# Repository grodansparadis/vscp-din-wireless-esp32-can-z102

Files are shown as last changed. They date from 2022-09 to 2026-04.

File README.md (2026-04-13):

# vscp-din-wireless-esp32-can-z102



This board has secure wireless wifi gateway functionality for a remote **CAN4VSCP** bus.

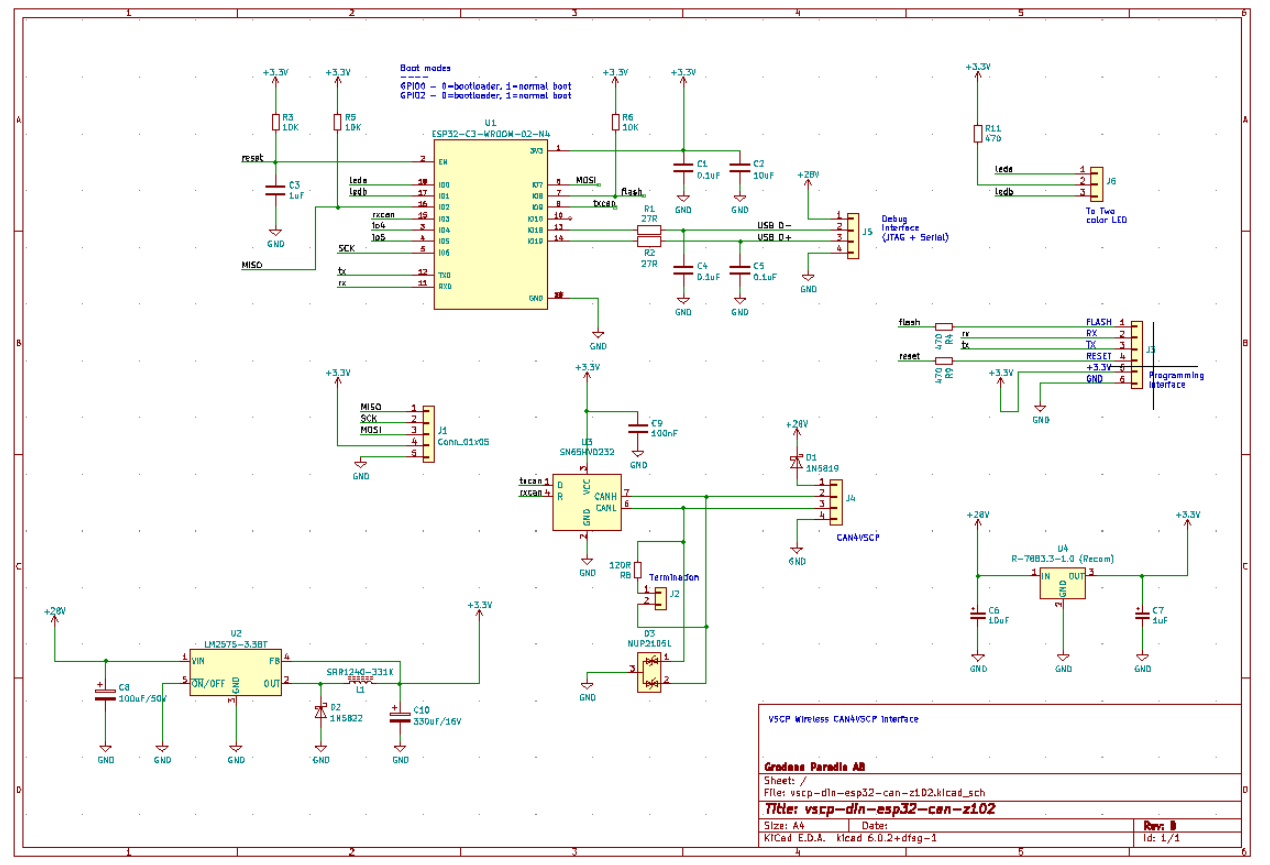
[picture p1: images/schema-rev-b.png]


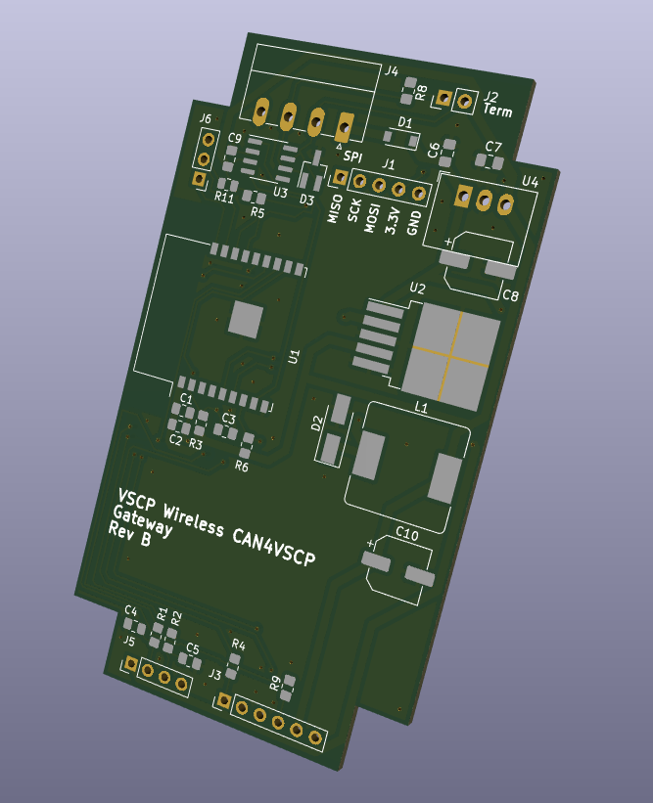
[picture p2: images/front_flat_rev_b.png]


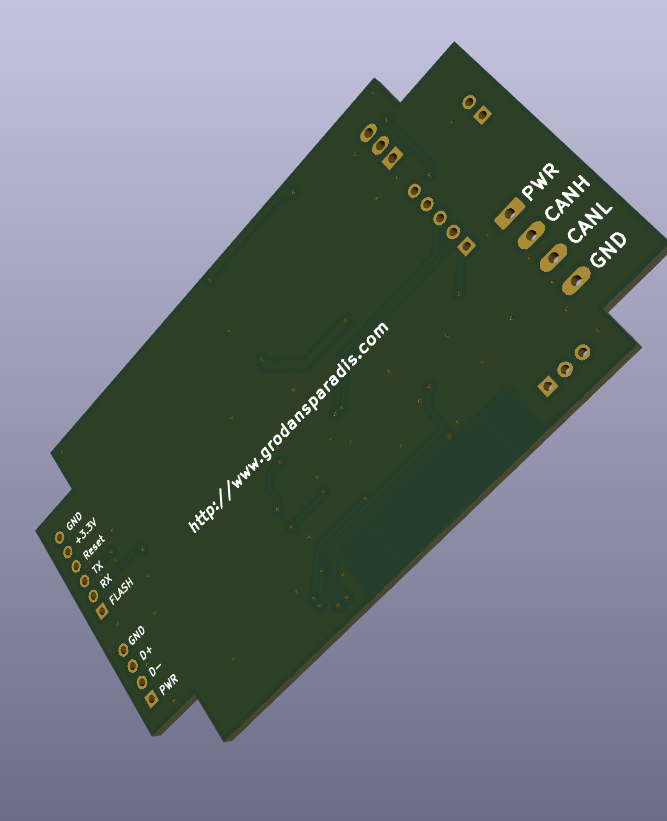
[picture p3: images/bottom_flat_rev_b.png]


Part of the [VSCP Project](https://www.vscp.org).

Copyright 2021-2026 (C) Åke Hedman, [https://www.grodansparadis.com](Grodans Paradis AB)
Licensed under the MIT License. See LICENSE file in the project root for full license information.

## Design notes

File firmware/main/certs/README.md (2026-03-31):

# Certificates Directory Convention

Certificate and key file convention for this directory:

- Tracked example or demo material should use the suffix `.example.pem`.
- Real local private keys should use either `prvtkey.pem` or `*.local.pem` and must stay untracked.
- Public demo certificates may be tracked when they are intentionally non-sensitive.

Recommended usage:

1. Keep tracked examples clearly marked, such as `prvtkey.example.pem`.
2. Copy an example to a local filename before use.
3. Never commit real private key contents to this repository.

Examples:

- `prvtkey.example.pem`: tracked placeholder or demo key material.
- `prvtkey.pem`: local private key, ignored by git.
- `device-cert.local.pem`: local certificate or key material, ignored by git.

The focused Codacy and Trivy setup assumes that tracked files in this directory are examples or public material, while real private keys remain local only.

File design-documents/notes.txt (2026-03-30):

Internal product page: http://192.168.1.7/wiki/doku.php?id=vscp-din-esp32-can-z102

openocd -f board/esp32c3-builtin.cfg

node test_ws1.js --url ws://192.168.1.100:8884/ws1

------------------------------------------------------
                       Security
------------------------------------------------------

https://community.letsencrypt.org/t/how-to-install-certificate-on-a-microcontroller/197377
Certificat bundle: https://docs.espressif.com/projects/esp-idf/en/stable/esp32/api-reference/protocols/esp_https_server.html

httpd_handle_t
start_webserver(void)
{
  httpd_handle_t srv     = NULL;
  httpd_ssl_config_t cfg = HTTPD_SSL_CONFIG_DEFAULT();
  cfg.port_insecure = g_persistent.webPort;
  cfg.httpd.server_port = g_persistent.webPort;

  // 4096 is to low for OTA
  cfg.httpd.stack_size = 1024 * 5;

  cfg.httpd.lru_purge_enable = true;
  // Use the URI wildcard matching function in order to
  // allow the same handler to respond to multiple different
  // target URIs which match the wildcard scheme
  cfg.httpd.uri_match_fn = httpd_uri_match_wildcard;

  cfg.httpd.max_uri_handlers = 20;

  extern const unsigned char servercert_start[] asm("_binary_servercert_pem_start");
  extern const unsigned char servercert_end[] asm("_binary_servercert_pem_end");
  cfg.servercert     = servercert_start;
  cfg.servercert_len = servercert_end - servercert_start;

  extern const unsigned char prvtkey_pem_start[] asm("_binary_prvtkey_pem_start");
  extern const unsigned char prvtkey_pem_end[] asm("_binary_prvtkey_pem_end");
  cfg.prvtkey_pem = prvtkey_pem_start;
  cfg.prvtkey_len = prvtkey_pem_end - prvtkey_pem_start;

  // Start the httpd server
  ESP_LOGD(TAG, "Starting httpd server on port: '%d' (insecure), '%d' (secure)", cfg.port_insecure, cfg.port_secure);

------------------------------------------------------
                       TODO
------------------------------------------------------
- Multicast support
- TLS support
- Websocket supportgit status

- Send heartbeat on Multicast 9598
- VSCP Node scan on VSCP2CAN interface.
- Buttons.  
- LED functionality.

Output pins - 
===========
WIFI
STATUS
BUS_OFF (optional): Outputs a low logic level (0 V) when the TWAI controller enters the bus-off state. Otherwise, it remains at a high logic level (3.3 V).

Input pins

Switches
========
1 - REST
2 - Contgrol

{
	"vscpHead":	96,
	"vscpClass":	10,
	"vscpType":	1,
	"vscpObid":	0,
	"vscpTimeStamp":	697851933,
	"vscpGUID":	"FF:FF:FF:FF:FF:FF:FF:FE:A0:76:4E:45:9E:7C:00:02",
	"vscpDateTime":	"0000-00-00T00:00:00",
	"vscpData":	[96, 0, 0, 0, 0]
}

send 0,20,3,,,,0:1:2:3:4:5:6:7:8:9:10:11:12:13:14:15,0,1,35

send 0,20,3,,2001-11-02T18:00:01,,-,0,1,35

send 0,20,3,,,,-,0,1,35

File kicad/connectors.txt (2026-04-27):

J1 (HIM-card/SPI)
==============================
1 - MISO
2 - SCK     --  Input Button
3 - MOSI    --  Input Button
4 - +3V     --  +3V to HIM card
5 - GND     --  GND to HIM card

J2 (HIM-card/SPI)
==============================
1 - MISO
2 - SCK
3 - MOSI
4 - +3V
5 - GND

J3 (programming()
==============================
1 - Flash
2 - RX
3 - TX
4 - Reser
5 - +5V
6 - GND

J4  (CAN)
==============================
1 - Power
2 - CANH
3 - CANL
4 - GND

J5 (Debug) 
==============================
1 - Power (NOT 5V !!!!!!!!)
2 - USB D-
3 - USB D+
4 - GND

J6 LED's
==============================
LED A - J6, 1  WiFi (green)
LED B - J6, 3  Status (blue)
GND   - J6, 2

J7 (Expansion)
==============================
1 - IO4
2 - IO5
3 - IO3
4 - RX
5 - TX

J8 Bus off LED
==============================
1 - LED power
2 - GND

J9 REST
==============================
1 - Reset
2 - GND

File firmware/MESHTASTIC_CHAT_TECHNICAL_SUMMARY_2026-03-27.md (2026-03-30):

# Technical Summary

Date: 2026-03-27

## Decision

Meshtastic was chosen as the better default fit for VSCP over MeshCore.

Reasons:

- More mature ecosystem for ESP32-based mesh deployments.
- Better tooling, documentation, and operational support.
- Lower integration and maintenance risk for a VSCP gateway.
- Faster path to a practical deployment.

MeshCore remains a valid option only if strict low-level control of transport framing and routing behavior is more important than ecosystem maturity and implementation cost.

## Transport Design

The recommended approach is to run VSCP over a compact application envelope on top of a mesh carrier.

Key design points:

- Compact binary mesh header.
- Fragmentation for larger VSCP events.
- Reassembly for inbound fragments.
- Duplicate suppression.
- QoS derived from VSCP priority.
- Conservative fragment size suitable for mesh transport.

Suggested mapping:

- High-priority VSCP traffic uses stronger delivery behavior.
- Lower-priority traffic uses best-effort delivery to limit airtime cost.

## Firmware Changes

Implemented a new VSCP mesh transport layer in the firmware.

Added:

- Mesh header encode/decode.
- Outbound fragmentation for VSCP event frames.
- Inbound reassembly with timeout-based slot management.
- Duplicate message suppression using source nickname and message id.
- VSCP-priority-to-QoS mapping.
- Integration with existing binary callback flow.

Behavioral integration:

- Outbound VSCP eventex traffic is routed through the mesh transport.
- Received VSCP events are converted to eventex and routed through the same path.
- The binary event handler was updated so it no longer returns success without forwarding the event.

Safety behavior:

- If no actual mesh transmit callback is registered, the code preserves previous behavior and does not fail the existing callback path.

## Files Changed

- [main/vscp-mesh.h](main/vscp-mesh.h)
- [main/vscp-mesh.c](main/vscp-mesh.c)
- [main/callbacks-binary.c](main/callbacks-binary.c)
- [main/vscp-binary.c](main/vscp-binary.c)
- [main/CMakeLists.txt](main/CMakeLists.txt)

## Validation

- The ESP32 firmware build completed successfully after the changes.

## Current Limitations

- No concrete Meshtastic TX adapter is wired yet.
- No concrete Meshtastic RX adapter is wired yet.
- ACK and retry scheduling are represented in the transport design, but a full retry scheduler is not yet implemented.

## Recommended Next Step

Connect the transport layer to a real Meshtastic send/receive interface so outbound packets go on-air and inbound mesh packets feed the reassembly path.

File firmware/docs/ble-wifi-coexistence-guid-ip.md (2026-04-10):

# BLE + Wi-Fi Coexistence and GUID/IP Advertising

This document describes the project-specific behavior implemented in this firmware for running BLE and Wi-Fi at the same time on ESP32-C3, and how GUID + IPv4 are broadcast over BLE advertising payloads.

## Summary

The firmware keeps BLE available after provisioning and advertises custom manufacturer payload data while Wi-Fi station mode is active.

- Coexistence is enabled in sdkconfig
- BLE remains available after provisioning
- Advertising payload contains GUID + IPv4
- Advertising payload is refreshed when a new STA IP is obtained

## What Is Advertised

Manufacturer payload format used by this firmware:

- 22 bytes total
- bytes [0..1]: Company ID (16-bit, little-endian)
- bytes [2..17]: node GUID (16 bytes)
- bytes [18..21]: IPv4 address (4 bytes, A.B.C.D order)

Example:

- GUID: 01:02:03:04:05:06:07:08:09:0A:0B:0C:0D:0E:0F:10
- IPv4: 192.168.1.42
- Company ID: 0xFFFF (default placeholder)
- Payload hex:
  FF FF 01 02 03 04 05 06 07 08 09 0A 0B 0C 0D 0E 0F 10 C0 A8 01 2A

## Lifecycle

### During Provisioning

- BLE provisioning transport is active (as before)
- custom provisioning endpoint VSCP-WCANG is available

### After Provisioning

- provisioning manager is deinitialized
- app BLE advertising is started through post-provision hook
- Wi-Fi stays in station mode

### On IP Change

- on IP_EVENT_STA_GOT_IP, advertising payload is rebuilt
- advertised IPv4 always follows current station IP

## Runtime Wi-Fi Power Save Control

Wi-Fi power save mode can be changed at runtime using the custom provisioning endpoint payload:

- WIFIPS:none
- WIFIPS:min
- WIFIPS:max

The selected mode is persisted in NVS key wifiPsMode and applied on next boot.

## Decoder Tools

### Decode raw manufacturer payload bytes

Use:

- tools/decode-ble-guid-ip.py "AA BB CC ..."
- echo "AA BB CC ..." | tools/decode-ble-guid-ip.py --stdin

Supported payload sizes:

- 22 bytes: CompanyID(2) + GUID(16) + IPv4(4) (default firmware format)
- 20 bytes: GUID(16) + IPv4(4) (legacy/compatibility)

### Decode directly from btmon/bluetoothctl logs

Use:

- btmon | tee /tmp/btmon.log
- tools/decode-ble-guid-ip-from-btmon.py --file /tmp/btmon.log

The btmon parser auto-extracts candidate payloads and prints decoded GUID/IP.

If btmon monitor mode is not permitted on your host, use the bluetoothctl fallback:

- tools/decode-ble-guid-ip-from-bluetoothctl.py --mac A0:76:4E:45:9E:7E --scan-time 15

You can also parse saved bluetoothctl text:

- tools/decode-ble-guid-ip-from-bluetoothctl.py --file /tmp/bluetoothctl-info.txt

## End-to-End Validation

Use the helper script:

- tools/validate-coex-flow.sh --port /dev/ttyUSB0 --monitor

The script performs build + flash and prints a coexistence checklist, including payload decode steps.

## Relevant Source Files

- main/main.c
- main/main.h
- main/CMakeLists.txt
- tools/validate-coex-flow.sh
- tools/decode-ble-guid-ip.py
- tools/decode-ble-guid-ip-from-btmon.py

## Notes

- Current advertising data is encoded as 22-byte manufacturer data with CompanyID(2) + GUID(16) + IPv4(4).
- Default Company ID in this firmware is 0xFFFF and should be replaced with an assigned value for production devices.

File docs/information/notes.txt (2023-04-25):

CAN Driver
----------
https://github.com/ThomasBarth/ESP32-CAN-Driver

CAN interface using ESP32
-------------------------
https://github.com/nopnop2002/esp-idf-CANBus-Monitor

Open standard for connecting devices to Wi-Fi using Bluetooth LE or Serial
--------------------------------------------------------------------------
https://www.improv-wifi.com/

BOX Z-102
=========

Etikett: 35 x 40 mm
HIM-card (upper card): 48 x 64

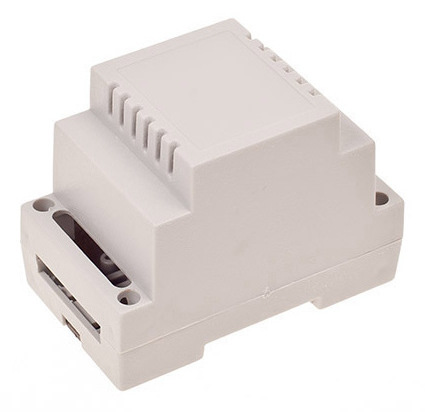
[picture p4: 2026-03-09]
design-documents/Z102_img/Z102_10.jpg

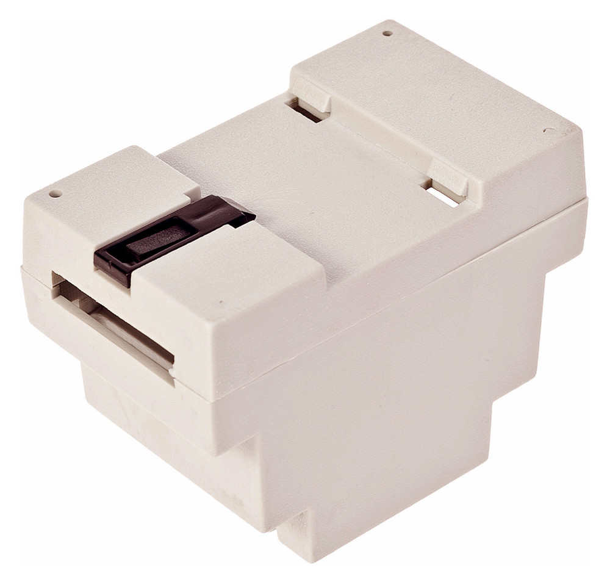
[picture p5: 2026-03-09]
design-documents/Z102_img/Z102_20.jpg

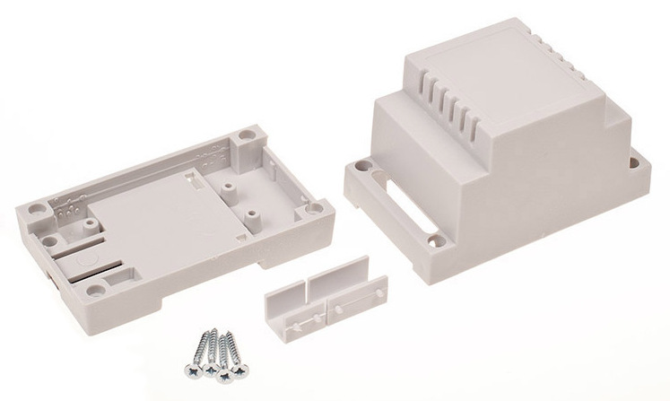
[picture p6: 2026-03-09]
design-documents/Z102_img/Z102_30.jpg

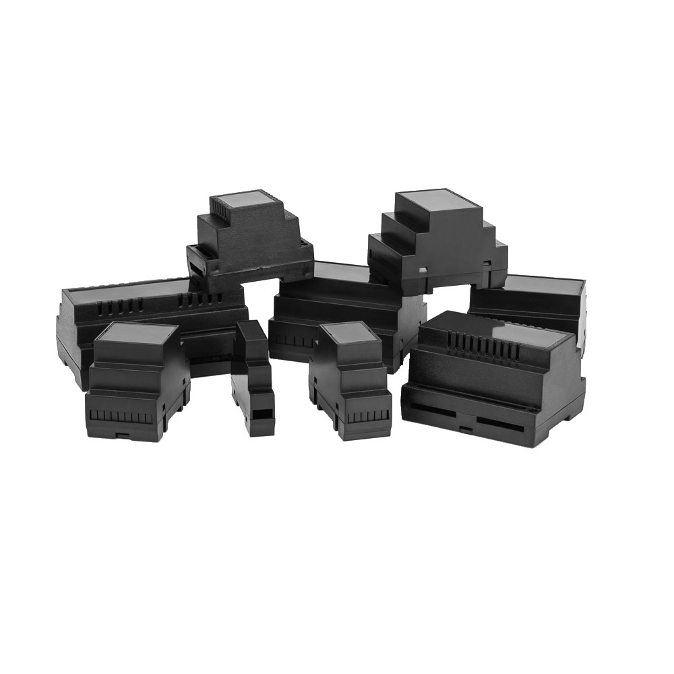
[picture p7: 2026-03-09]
design-documents/Z102_img/Z102_80.jpg

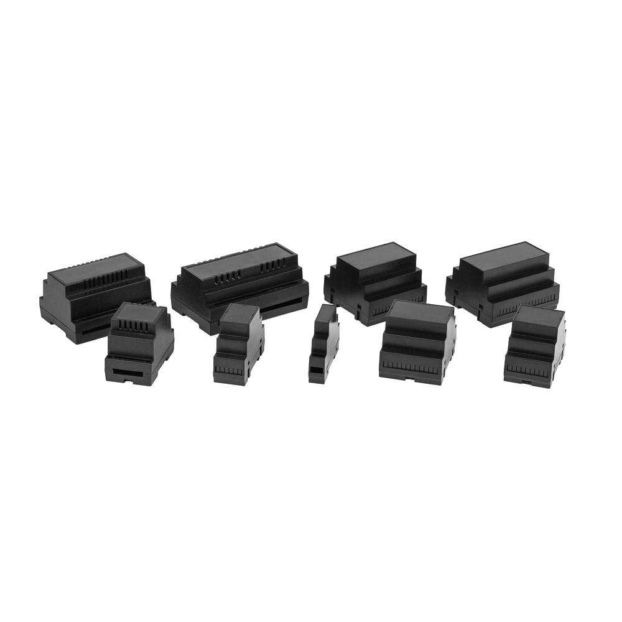
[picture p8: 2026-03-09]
design-documents/Z102_img/Z102_90.jpg

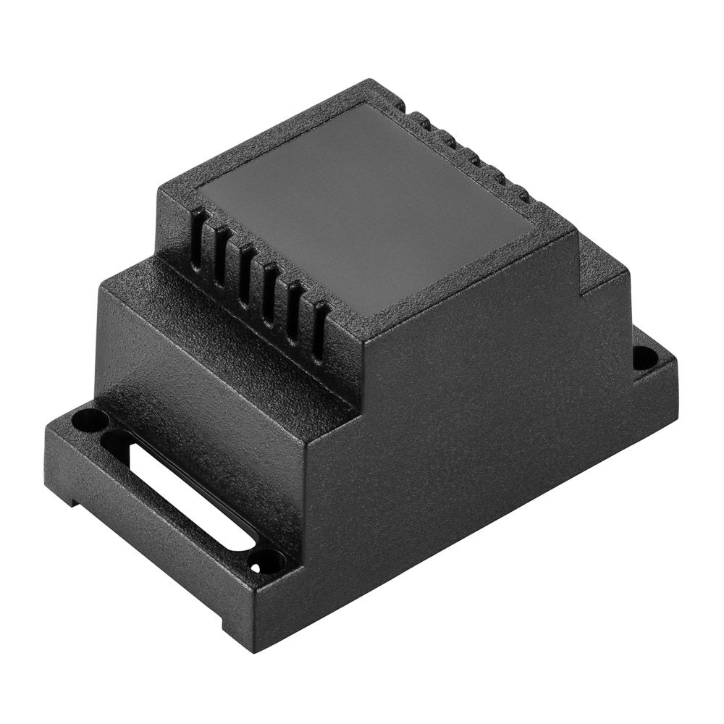
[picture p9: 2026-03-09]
design-documents/Z102_img/Z102_60.jpg

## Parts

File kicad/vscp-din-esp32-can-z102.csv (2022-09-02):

Source: | /usr/local/src/VSCP/vscp-din-wireless-esp32-can/vscp-din-esp32-can-z102.kicad_sch
Date: | ons 31 aug 2022 23:20:48
Tool: | Eeschema 6.0.2+dfsg-1
Generator: | /usr/share/kicad/plugins/bom_csv_grouped_by_value_with_fp.py
Component Count: | 32
Ref | Qnty | Value | Cmp name | Footprint | Description | Vendor
C1, C4, C5, | 3 | 0.1uF | C | Capacitor_SMD:C_0805_2012Metric | Unpolarized capacitor
C2, C6, | 2 | 10uF | CP_Small | Capacitor_SMD:C_1206_3216Metric
C3, | 1 | 1uF | C | Capacitor_SMD:C_0805_2012Metric | Unpolarized capacitor
C7, | 1 | 1uF | CP_Small | Capacitor_SMD:C_1206_3216Metric
C8, | 1 | 100uF/50V | C_Polarized | Capacitor_SMD:CP_Elec_6.3x9.9 | Polarized capacitor
C9, | 1 | 100nF | C | Capacitor_SMD:C_0805_2012Metric | Unpolarized capacitor
C10, | 1 | 330uF/16V | C_Polarized | Capacitor_SMD:CP_Elec_6.3x9.9 | Polarized capacitor
D1, | 1 | 1N5819 | 1N5819 | Diode_SMD:D_SOD-123 | 40V 1A Schottky Barrier Rectifier Diode, DO-41
D2, | 1 | 1N5822 | 1N5822 | Diode_THT:D_DO-201AD_P15.24mm_Horizontal | 40V 3A Schottky Barrier Rectifier Diode, DO-201AD
D3, | 1 | NUP2105L | NUP2105L | Package_TO_SOT_SMD:SOT-23 | Dual Line CAN Bus Protector, 24Vrwm
J2, | 1 | Conn_01x02 | Conn_01x02 | Connector_PinHeader_2.54mm:PinHeader_1x02_P2.54mm_Vertical | Generic connector, single row, 01x02, script generated (kicad-library-utils/schlib/autogen/connector/)
J3, | 1 | Conn_01x06 | Conn_01x06 | Connector_PinHeader_2.54mm:PinHeader_1x06_P2.54mm_Vertical | Generic connector, single row, 01x06, script generated (kicad-library-utils/schlib/autogen/connector/)
J4, | 1 | Conn_01x04 | Conn_01x04 | Connector_Phoenix_MC:PhoenixContact_MC_1,5_4-G-3.81_1x04_P3.81mm_Horizontal | Generic connector, single row, 01x04, script generated (kicad-library-utils/schlib/autogen/connector/)
J5, | 1 | Conn_01x04 | Conn_01x04 | Connector_PinHeader_2.54mm:PinHeader_1x04_P2.54mm_Vertical | Generic connector, single row, 01x04, script generated (kicad-library-utils/schlib/autogen/connector/)
J6, | 1 | Conn_01x03 | Conn_01x03 | Connector_PinHeader_2.54mm:PinHeader_1x03_P2.54mm_Vertical | Generic connector, single row, 01x03, script generated (kicad-library-utils/schlib/autogen/connector/)
L1, | 1 | SRR1240-331K | L_Ferrite | Inductor_SMD:L_Bourns_SRR1260 | Inductor with ferrite core
L2, | 1 | L_Ferrite | L_Ferrite |  | Inductor with ferrite core
R1, R2, | 2 | 27R | R | Resistor_SMD:R_0805_2012Metric | Resistor
R3, R5, R6, | 3 | 10K | R_Small | Resistor_SMD:R_0805_2012Metric | Resistor, small symbol
R8, | 1 | 120R | R_Small | Resistor_SMD:R_0805_2012Metric | Resistor, small symbol
R9, R11, | 2 | 470 | R_Small | Resistor_SMD:R_0805_2012Metric | Resistor, small symbol
U1, | 1 | ESP32-C3-MINI-1-N4 | ESP32-C3-MINI-1-N4 | XCVR_ESP32-C3-MINI-1-N4
U2, | 1 | LM2575-3.3BT | LM2575-3.3BT | Package_TO_SOT_SMD:TO-263-5_TabPin3 | Fixed 3.3V 52kHz Simple 1A Buck Regulator, TO-220-5
U3, | 1 | SN65HVD232 | SN65HVD232 | Package_SO:SOIC-8_3.9x4.9mm_P1.27mm | CAN Bus Transceivers, 3.3V, 1Mbps, SOIC-8
U4, | 1 | R-78B3.3-1.0 (Recom) | R-78B3.3-2.0 | Converter_DCDC:Converter_DCDC_RECOM_R-78B-2.0_THT | 2A Step-Down DC/DC-Regulator, 4.75-32V input, 3.3V fixed Output Voltage, LM78xx replacement, -40°C to +85°C, SIP3

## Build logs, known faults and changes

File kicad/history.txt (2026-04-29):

HISTORY
-------
260428 - Changed D4 from 1N5822 to 1N5819
260427 - Added legend for LED's
260128 - Changed to "rev C" on board and on drawing.
230424 - Rev C
230424 - Added scotty diod to USB power input.
230423 - Added connector for reset button (J9)
220925 - Added connector and resistor for BUS_OFF LED connector. (J8)
220923 - Changed Diod connecter to common catode
220923 - Populated J7 (IO3/IO4/IO5/RX/TX)
220923 - rxcan moved back to IO10 from IO3
220923 - Added J7 expansion connector (pairs with J1)
220920 - J4 moved closer to edge.
220910 - Rev B started. 
220910 - rxcan moved from IO10 to IO3
220916 - txcan routed to Flash pin instead of io8

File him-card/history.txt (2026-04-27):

2026-04-27 AKHE - Changed value of R3 to 200 ohm. Set final colors for LED's.

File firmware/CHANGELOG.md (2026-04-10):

# Changelog

## 2026-04-10

### Added

- BLE post-provision advertising implementation for ESP32-C3 using NimBLE.
- Manufacturer advertisement payload with device identity and network address.
- Runtime Wi-Fi power-save control via provisioning endpoint commands:
  - WIFIPS:none
  - WIFIPS:min
  - WIFIPS:max
- Validation helpers:
  - tools/validate-coex-flow.sh
  - tools/decode-ble-guid-ip.py
  - tools/decode-ble-guid-ip-from-btmon.py
  - tools/decode-ble-guid-ip-from-bluetoothctl.py
- Documentation:
  - docs/ble-wifi-coexistence-guid-ip.md

### Changed

- BLE manufacturer payload format updated to 22 bytes:
  - CompanyID(2, little-endian) + GUID(16) + IPv4(4)
- Advertising payload refresh now occurs after IP_EVENT_STA_GOT_IP.
- BLE advertising is kept available after provisioning (coexists with Wi-Fi STA).
- README updated to point to detailed coexistence documentation.

### Fixed

- NimBLE startup path hardened to avoid startup failure when BLE host state is already initialized.
- Header macro conflicts with NimBLE logging defines resolved by namespacing project log-level constants.

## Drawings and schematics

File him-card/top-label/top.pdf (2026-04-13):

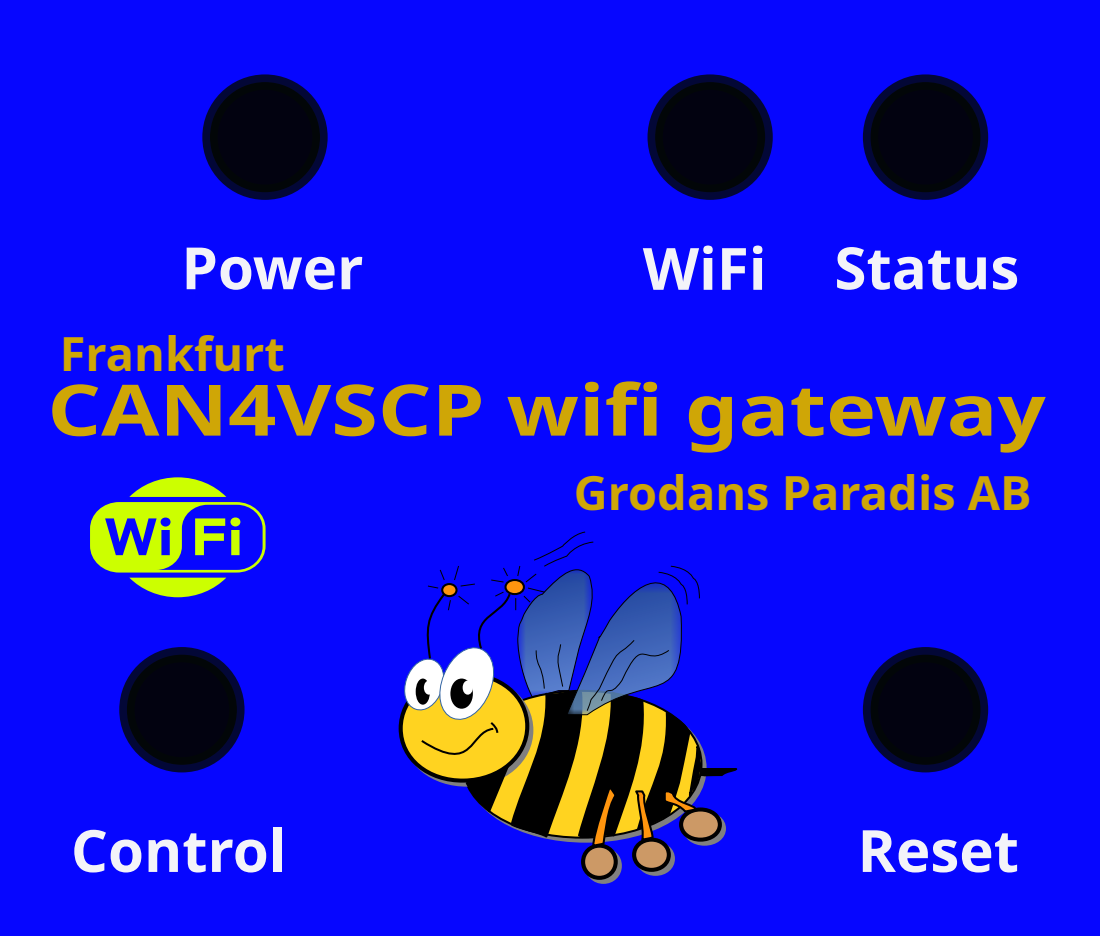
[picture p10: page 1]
Control; Reset; Power; WiFi Status

CAN4VSCP wifi gateway Frankfurt

Grodans Paradis AB

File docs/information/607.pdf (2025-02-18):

# Product Specification

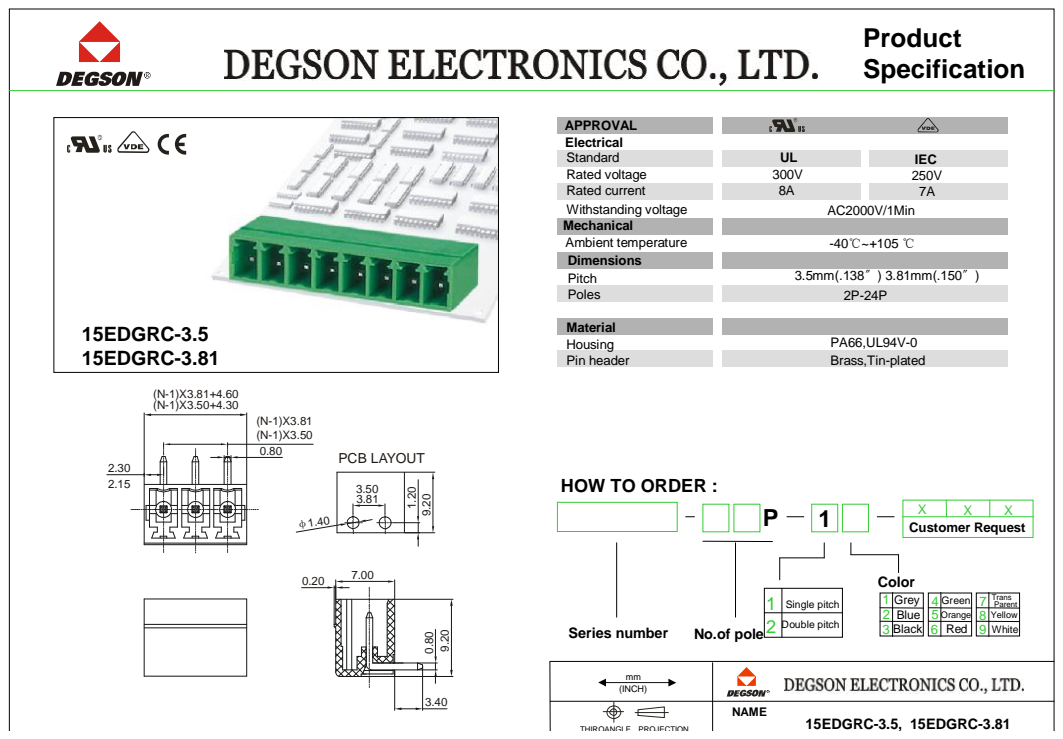
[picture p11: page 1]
NAME; Single pitch; (INCH); THIROANGLE PROJECTION; 15EDGRC-3.5 15EDGRC-3.81; Electrical Standard Rated voltage Rated current Withstanding voltage Mechanical Ambient temperature Dimensions Pitch Poles; Material Housing; Pin header; Brass,Tin-plated; AC2000V/1Min; IEC; 15EDGRC-3.5, 15EDGRC-3.81; PCB LAYOUT; APPROVAL; Customer Request; Series number; Color 1 Grey 2 3; Blue Black; Green; Orange Red; Trans Parent; Yellow White

HOW TO ORDER :

Double pitch No.of pole

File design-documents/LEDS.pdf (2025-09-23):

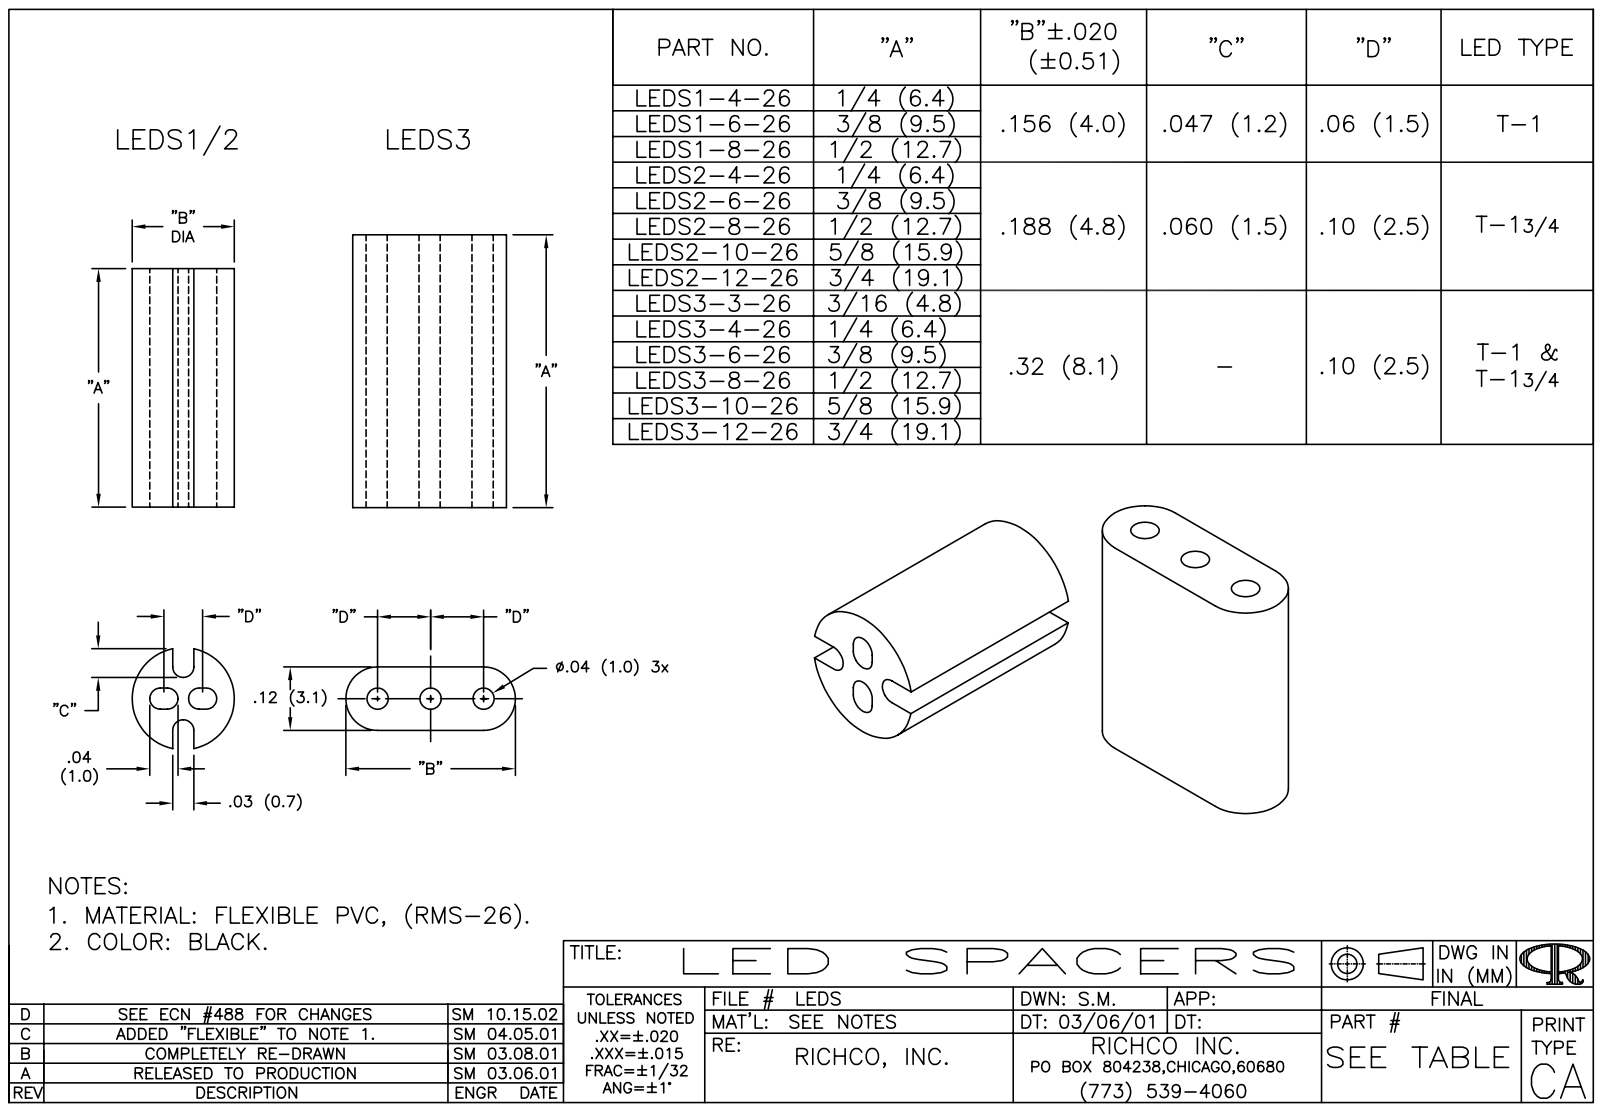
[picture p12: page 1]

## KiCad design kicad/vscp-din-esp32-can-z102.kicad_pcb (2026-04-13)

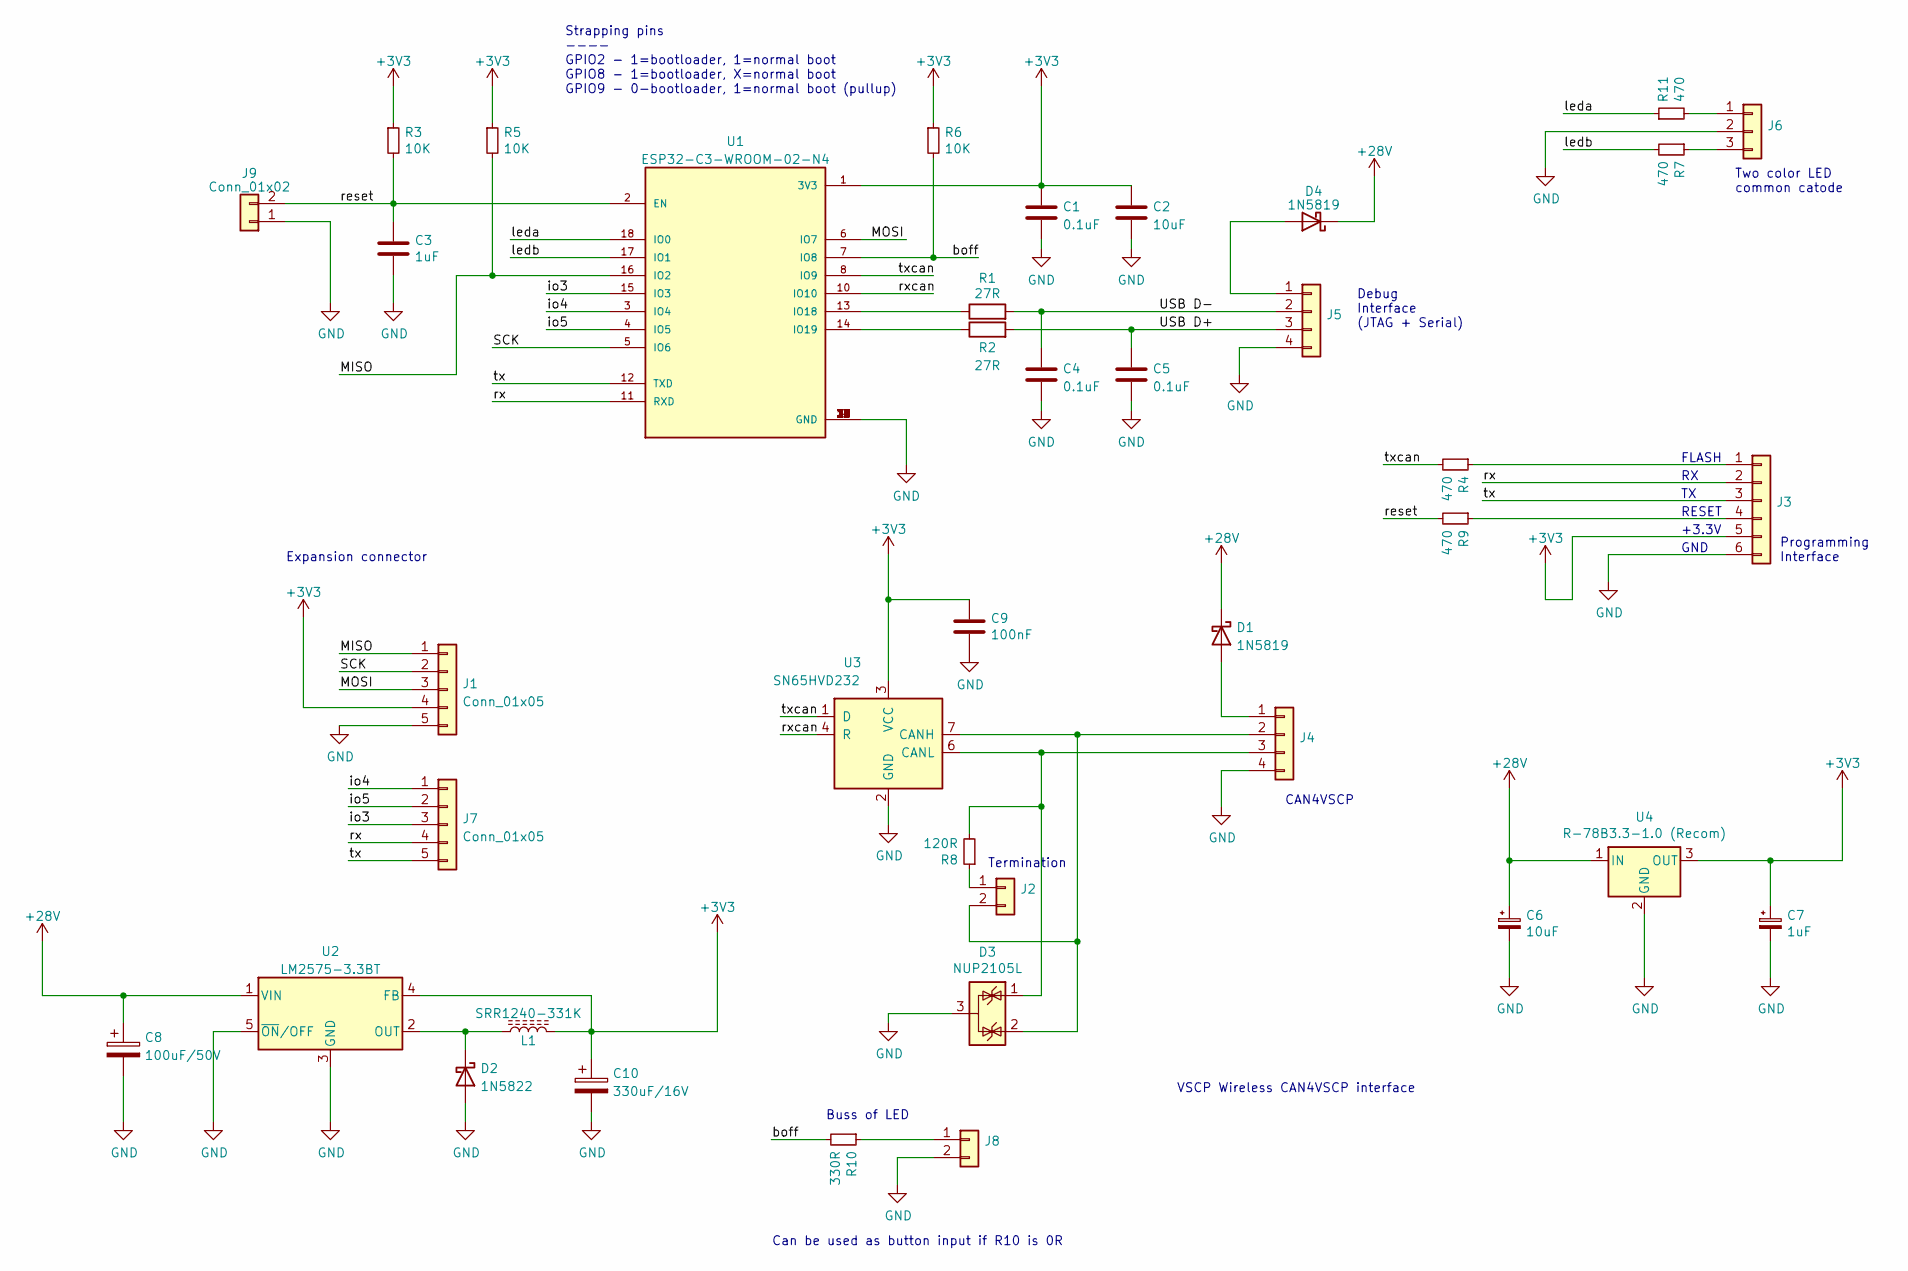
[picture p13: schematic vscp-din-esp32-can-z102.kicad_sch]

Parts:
C1, C4, C5: 0.1uF; C_0805_2012Metric_Pad1.18x1.45mm_HandSolder
C2, C6: 10uF; C_0805_2012Metric_Pad1.18x1.45mm_HandSolder
C3, C7: 1uF; C_0805_2012Metric_Pad1.18x1.45mm_HandSolder
C8: 100uF/50V; CP_Elec_6.3x9.9
C9: 100nF; C_0805_2012Metric_Pad1.18x1.45mm_HandSolder
C10: 330uF/16V; CP_Elec_6.3x9.9
D1, D4: 1N5819; D_SOD-123
D2: 1N5822; D_SMA_Handsoldering
D3: NUP2105L; SOT-23_Handsoldering
J1, J7: Conn_01x05; PinHeader_1x05_P2.54mm_Vertical
J2, J8, J9: Conn_01x02; PinHeader_1x02_P2.54mm_Vertical
J3: Conn_01x06; PinHeader_1x06_P2.54mm_Vertical
J4: Conn_01x04; PhoenixContact_MC_1,5_4-G-3.81_1x04_P3.81mm_Horizontal
J5: Conn_01x04; PinHeader_1x04_P2.54mm_Vertical
J6: Conn_01x03; PinHeader_1x03_P2.54mm_Vertical
L1: SRR1240-331K; L_Bourns_SRR1260
R1, R2: 27R; R_0805_2012Metric_Pad1.20x1.40mm_HandSolder
R3, R5, R6: 10K; R_0805_2012Metric_Pad1.20x1.40mm_HandSolder
R4, R9: 470; R_0805_2012Metric_Pad1.20x1.40mm_HandSolder
R7, R11: 470; R_0805_2012Metric
R8: 120R; R_0805_2012Metric_Pad1.20x1.40mm_HandSolder
R10: 330R; R_0805_2012Metric_Pad1.20x1.40mm_HandSolder
U1: ESP32-C3-WROOM-02-N4; ESP-WROOM-02
U2: LM2575-3.3BT; TO-263-5_TabPin3
U3: SN65HVD232; SOIC-8_3.9x4.9mm_P1.27mm
U4: R-78B3.3-1.0 (Recom); Converter_DCDC_RECOM_R-78B-2.0_THT

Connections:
+3V3: C1.1, C2.1, C7.1, C9.1, C10.1, J1.4, J3.5, L1.2, R3.1, R5.1, R6.1, U1.1 (3V3), U2.4 (FB), U3.3 (VCC), U4.3 (OUT)
+28V: C6.1, C8.1, D1.1 (K), D4.1 (K), U2.1 (VIN), U4.1 (IN)
/MISO: J1.1, R5.2, U1.16 (IO2)
/MOSI: J1.3, U1.6 (IO7)
/SCK: J1.2, U1.5 (IO6)
/USB D+: C5.1, J5.3, R2.2
/USB D-: C4.1, J5.2, R1.2
/boff: R6.2, R10.2, U1.7 (IO8)
/io3: J7.3, U1.15 (IO3)
/io4: J7.1, U1.3 (IO4)
/io5: J7.2, U1.4 (IO5)
/leda: R11.1, U1.18 (IO0)
/ledb: R7.2, U1.17 (IO1)
/reset: C3.1, J9.2, R3.2, R9.2, U1.2 (EN)
/rx: J3.2, J7.4, U1.11 (RXD)
/rxcan: U1.10 (IO10), U3.4 (R)
/tx: J3.3, J7.5, U1.12 (TXD)
/txcan: R4.2, U1.8 (IO9), U3.1 (D)
GND: C1.2, C2.2, C3.2, C4.2, C5.2, C6.2, C7.2, C8.2, C9.2, C10.2, D2.2 (A), D3.3 (A), J1.5, J3.6, J4.4, J5.4, J6.2, J8.2, J9.1, U1.9 (GND), U1.19 (GND), U1.20 (GND), U1.21 (GND), U1.22 (GND), U1.23 (GND), U1.24 (GND), U1.25 (GND), U1.26 (GND), U1.27 (GND), U1.28 (GND), U1.29 (GND), U1.30 (GND), U1.31 (GND), U1.32 (GND), U1.33 (GND), U1.34 (GND), U1.35 (GND), U1.36 (GND), U1.37 (GND), U1.38 (GND), U1.39 (GND), U2.3 (GND), U2.5 (~ON/OFF), U3.2 (GND), U4.2 (GND)
unnamed: D1.2 (A), J4.1
unnamed: D2.1 (K), L1.1, U2.2 (OUT)
unnamed: D4.2 (A), J5.1
unnamed: J2.1, R8.1
unnamed: D3.2 (K), J2.2, J4.2, U3.7 (CANH)
unnamed: J3.1, R4.1
unnamed: J3.4, R9.1
unnamed: D3.1 (K), J4.3, R8.2, U3.6 (CANL)
unnamed: J6.1, R11.2
unnamed: J6.3, R7.1
unnamed: J8.1, R10.1
unnamed: R1.1, U1.13 (IO18)
unnamed: R2.1, U1.14 (IO19)

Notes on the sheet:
VSCP Wireless CAN4VSCP interface
Termination
RESET
CAN4VSCP
Debug Interface (JTAG + Serial)
Buss of LED
Can be used as button input if R10 is 0R
Strapping pins ---- GPIO2 - 1=bootloader, 1=normal boot GPIO8 - 1=bootloader, X=normal boot GPIO9 - 0-bootloader, 1=normal boot (pullup)
+3.3V
Programming Interface
GND
Two color LED common catode
FLASH
Expansion connector

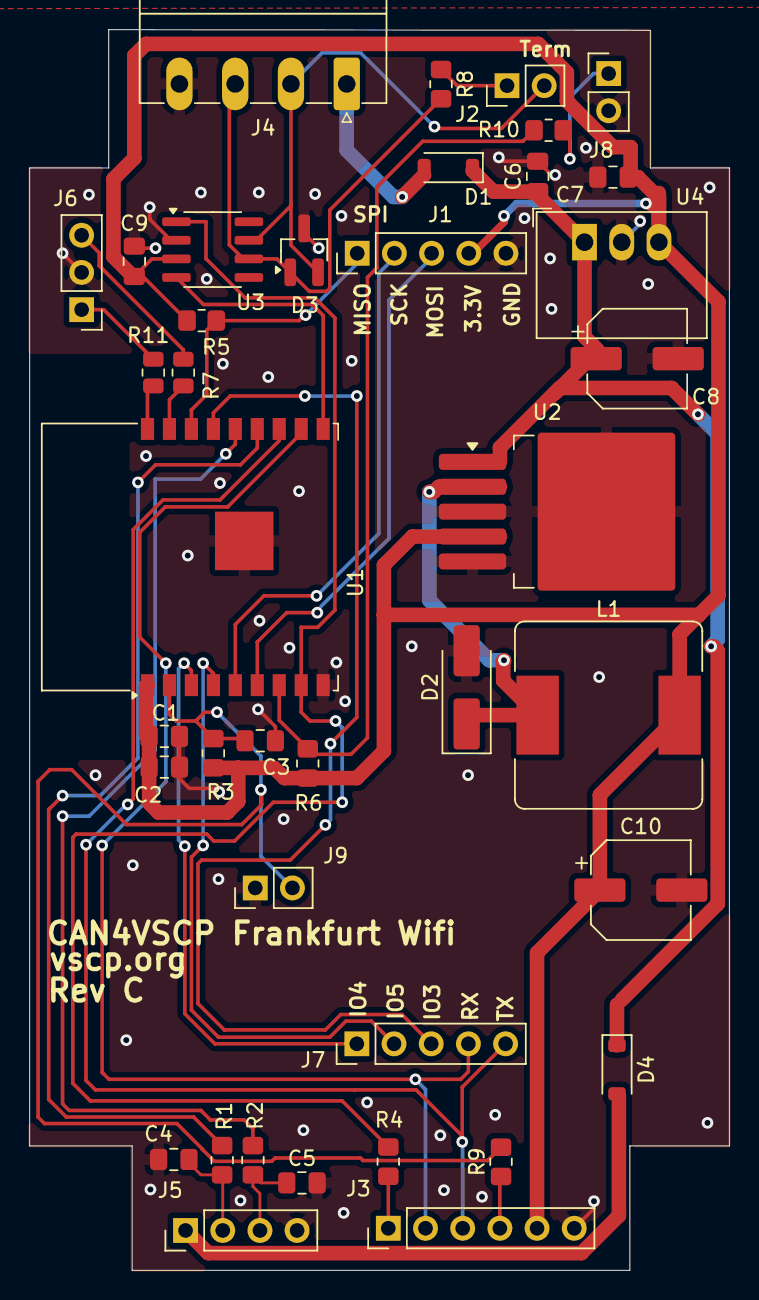
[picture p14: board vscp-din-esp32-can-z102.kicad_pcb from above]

Board: 2 copper layers, 47.8 x 84.8 mm, 39 parts (0 on the bottom side), 32 nets.

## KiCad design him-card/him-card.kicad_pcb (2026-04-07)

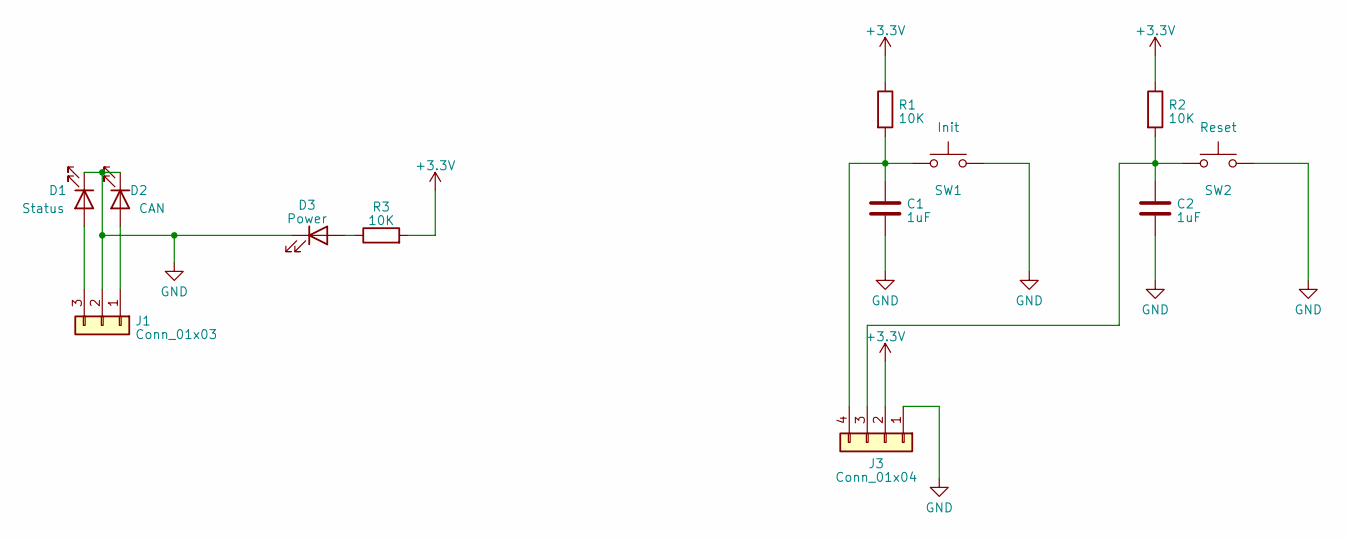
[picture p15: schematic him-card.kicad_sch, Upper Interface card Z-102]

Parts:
C1, C2: 1uF; C_0805_2012Metric_Pad1.18x1.45mm_HandSolder
D1: Status; LED_D3.0mm
D2: CAN; LED_D3.0mm
D3: Power; LED_D3.0mm
J1: Conn_01x03; PinHeader_1x03_P2.54mm_Vertical
J3: Conn_01x04; PinHeader_1x04_P2.54mm_Vertical
R1, R2, R3: 10K; R_0805_2012Metric_Pad1.20x1.40mm_HandSolder
SW1: Init; SW_Tactile_Straight_KSL0Axx1LFTR
SW2: Reset; SW_Tactile_Straight_KSL0Axx1LFTR

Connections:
+3.3V: J3.2, R1.1, R2.1, R3.2
GND: C1.2, C2.2, D1.1 (K), D2.1 (K), D3.1 (K), J1.2, J3.1, SW1.2, SW2.2
unnamed: D1.2 (A), J1.3
unnamed: D2.2 (A), J1.1
unnamed: D3.2 (A), R3.1
unnamed: C2.1, J3.3, R2.2, SW2.1
unnamed: C1.1, J3.4, R1.2, SW1.1

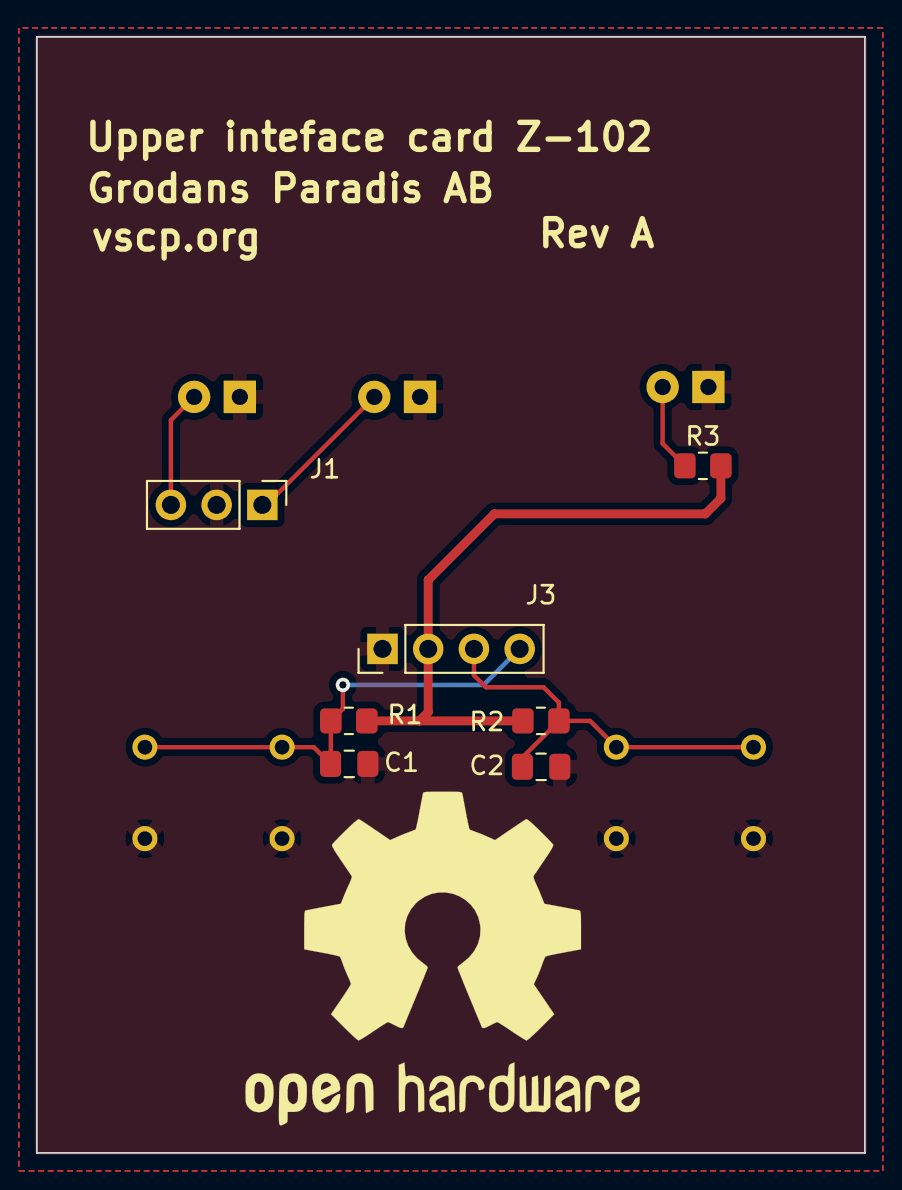
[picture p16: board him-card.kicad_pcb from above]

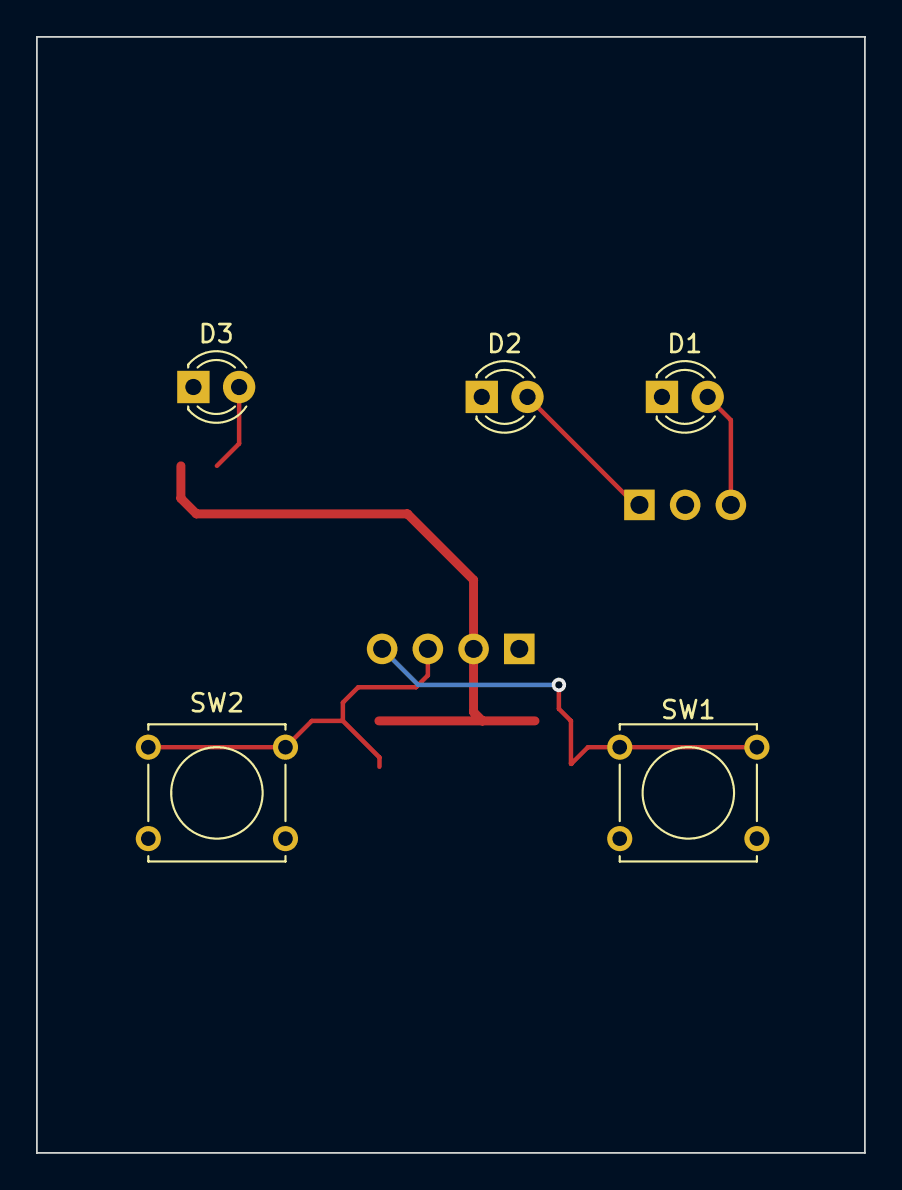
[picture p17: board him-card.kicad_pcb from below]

Board: 2 copper layers, 46.0 x 62.0 mm, 12 parts (5 on the bottom side), 7 nets.

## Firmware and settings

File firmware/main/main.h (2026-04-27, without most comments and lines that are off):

#include <esp_log.h>
#include <nvs.h>
#define __VSCP_WCANG_H__
#include <freertos/FreeRTOS.h>
#include <freertos/task.h>
#include <freertos/queue.h>
#include "vscp.h"
#include "can4vscp.h"
#define TWAI_TX_GPIO_NUM GPIO_NUM_9  // CAN TX
#define TWAI_RX_GPIO_NUM GPIO_NUM_10 // CAN RX
#define LED_WIFI_GPIO 0
#define LED_STATUS_GPIO    1
#define GPIO_OUTPUT_PIN_SEL    ((1ULL << LED_WIFI_GPIO) | (1ULL << LED_STATUS_GPIO))
#define DEV_BUFFER_LENGTH 64
#define NVS_GET_OR_SET_DEFAULT(type, nvs_get_fn, nvs_set_fn, handle, key, var, defval, logtag, valfmt)                 \
  do {                                                                                                                 \
    esp_err_t _rv = nvs_get_fn((handle), (key), &(var));                                                               \
    switch (_rv) {                                                                                                     \
      case ESP_OK:                                                                                                     \
        ESP_LOGI((logtag), key ": " valfmt, (var));                                                                    \
        break;                                                                                                         \
      case ESP_ERR_NVS_NOT_FOUND:                                                                                      \
        ESP_LOGI((logtag), key " not found in nvs, writing default");                                                  \
        (var) = (defval);                                                                                              \
        nvs_set_fn((handle), (key), (defval));                                                                         \
        break;                                                                                                         \
      default:                                                                                                         \
        ESP_LOGI((logtag), "Error (%s) reading " key " from nvs!", esp_err_to_name(_rv));                              \
        break;                                                                                                         \
    }                                                                                                                  \
  } while (0)
#define NVS_GET_OR_SET_DEFAULT_STR(handle, key, var, defval, logtag)                                                   \
  do {                                                                                                                 \
    size_t _len   = sizeof(var);                                                                                       \
    esp_err_t _rv = nvs_get_str((handle), (key), (var), &_len);                                                        \
    switch (_rv) {                                                                                                     \
      case ESP_OK:                                                                                                     \
        ESP_LOGI((logtag), key ": %s", (var));                                                                         \
        break;                                                                                                         \
      case ESP_ERR_NVS_NOT_FOUND:                                                                                      \
        ESP_LOGI((logtag), key " not found in nvs, writing default");                                                  \
        strncpy((var), (defval), sizeof(var));                                                                         \
        nvs_set_str((handle), (key), (defval));                                                                        \
        break;                                                                                                         \
      default:                                                                                                         \
        ESP_LOGI((logtag), "Error (%s) reading " key " from nvs!", esp_err_to_name(_rv));                              \
        break;                                                                                                         \
    }                                                                                                                  \
  } while (0)
typedef enum {
  CH_LINK = 0, // tcp/ip link protocol
  CH_CAN,      // CAN
  CH_WS,       // websocket I & II
  CH_UDP,      // UDP
  CH_MULTI,    // Multicast
  CH_MQTT,     // MQTT
  CH_BLE,      // BLE
  CH_UART      // UART
} dev_channel_t;
typedef struct {
  union {
    struct {
      uint32_t active : 1;
      uint32_t open : 1;
      uint32_t reserved : 30;
    };
    uint32_t flags;
  };
  QueueHandle_t tocan_queue;
  QueueHandle_t fromcan_queue;
  uint32_t overruns;
} transport_t;
#define DEFAULT_KEY_LEN 32 // AES256
#define DEFAULT_GUID    "" // Empty constructs from MAC, "-" all nills, "xx:yy:..." set GUID
#define DEFAULT_BLE_ENABLE       true
#define DEFAULT_ADVERTISE_ENABLE true
#define DEFAULT_TWAI_MODE  0 // CAN4VSCP_NORMAL
#define DEFAULT_TWAI_SPEED CAN4VSCP_125K
#define DEFAULT_SMTP_ENABLE false
#define DEFAULT_APP_OTA_URL_MAX_SIZE 128
#define DEFAULT_APP_OTA_URL          "http://vscp.org/firmware/vscp-can4vscp-gw/firmware.bin"
#define DEFAULT_TCPIP_VER 4 // Ipv6 = 6 or Ipv4 = 4
#define TCPSRV_WELCOME_MSG                                                                                             \
  "Welcome to the VSCP CAN4VSCP Gateway\r\n"                                                                           \
  "Copyright (C) 2000-2026 Grodans Paradis AB\r\n"                                                                     \
  "https://www.grodansparadis.com\r\n"                                                                                 \
  "+OK\r\n"
#define LOG_TYPE_NONE 0
#define LOG_TYPE_STD  1
#define LOG_TYPE_UDP  2
#define LOG_TYPE_TCP  3
#define LOG_TYPE_HTTP 4
#define LOG_TYPE_MQTT 5
#define LOG_TYPE_VSCP 6
#define LOG_LEVEL_NONE    0 // No logging
#define LOG_LEVEL_ERROR   1 // Errors only
#define LOG_LEVEL_WARNING 2 // Warnings
#define LOG_LEVEL_INFO    3 // Information
#define LOG_LEVEL_DEBUG   4 // Debugging
#define LOG_LEVEL_VERBOSE 5 // Verbose debugging
#define DEFAULT_NODE_NAME        "VSCP CAN4VSCP Gateway"
#define DEFAULT_ENCRYPTION_LEVEL VSCP_ENCRYPTION_NONE // 0 = none, 1 = AES128, 2 = AES192, 3 = AES256
#define DEFAULT_MODULE_ZONE      0  // VSCP zone for module
#define DEFAULT_MODULE_SUBZONE   0  // VSCP subzone for module
#define DEFAULT_LOG_URL  " "
#define DEFAULT_LOG_PORT 514
#define DEFAULT_CAN_MODE   0          // CAN4VSCP_NORMAL
#define DEFAULT_CAN_SPEED  6          // CAN4VSCP_125K
#define DEFAULT_CAN_FILTER 0xFFFFFFFF // Accept all
#define DEFAULT_CAN_RAW    false       // Send and understand raw CAN frames
#define DEFAULT_LOG_TYPE         LOG_TYPE_STD
#define DEFAULT_LOG_LEVEL        0
#define DEFAULT_LOG_RETRIES      3
#define DEFAULT_WEBSERVER_PORT     80
#define DEFAULT_WEBSERVER_USER     "vscp"
#define DEFAULT_WEBSERVER_PASSWORD "secret"
#define DEFAULT_VSCP_LINK_ENABLE   true
#define DEFAULT_VSCP_LINK_PORT     9598
#define DEFAULT_VSCP_LINK_USER     "vscp"
#define DEFAULT_VSCP_LINK_PASSWORD "secret"
#define DEFAULT_MQTT_ENABLE            false
#define DEFAULT_MQTT_LOGGING_ENABLE    false
#define DEFAULT_MQTT_TLS_ENABLE        false
#define DEFAULT_MQTT_URL               "mqtt://"
#define DEFAULT_MQTT_PORT              1883
#define DEFAULT_MQTT_USER              ""
#define DEFAULT_MQTT_PASSWORD          ""
#define DEFAULT_MQTT_PUBLISH           "vscp/{{guid}}/{{class}}/{{type}}/{{sindex}}"
#define DEFAULT_MQTT_SUBSCRIBE         "can4vscpgw/{{guid}}"
#define DEFAULT_MQTT_LOG_PUBLISH_TOPIC "can4vscpgw/{{guid}}/log"
#define DEFAULT_MQTT_CLIENT_ID         "vscp-can4vscpgw"
#define DEFAULT_MQTT_CA_CERT           ""
#define DEFAULT_MQTT_CLIENT_CERT       ""
#define DEFAULT_MQTT_CLIENT_KEY        ""
#define DEFAULT_MQTT_QOS               0
#define DEFAULT_MQTT_RETAIN            false
#define DEFAULT_MQTT_FORMAT            MQTT_FORMAT_JSON
#define DEFAULT_MULTICAST_ENABLE     false
#define DEFAULT_MULTICAST_URL        "224.0.23.158"
#define DEFAULT_MULTICAST_PORT       9598
#define DEFAULT_MULTICAST_TTL        10
#define DEFAULT_MULTICAST_ENCRYPTION false
#define DEFAULT_MULTICAST_HEARTBEAT  true
#define DEFAULT_UDP_RX_ENABLE  false
#define DEFAULT_UDP_TX_ENABLE  false
#define DEFAULT_UDP_URL        "255.255.255.255" // Broadcast
#define DEFAULT_UDP_PORT       33333
#define DEFAULT_UDP_ENCRYPTION false
#define DEFAULT_WEBSOCKETS_ENABLE   false
#define DEFAULT_WEBSOCKETS_PORT     8884
#define DEFAULT_WEBSOCKETS_USER     "vscp"
#define DEFAULT_WEBSOCKETS_PASSWORD "secret"
#define DEFAULT_WIFI_STATIC_ENABLE  0
#define DEFAULT_WIFI_STATIC_IP      ""
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

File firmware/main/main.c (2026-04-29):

extern void
twai_transmit_task(void *arg);
/*
  File: main.c

  VSCP Wireless CAN4VSCP Gateway

  Main application entry point and system initialization for ESP32-C3 based
  VSCP CAN gateway with WiFi connectivity. This module handles:

  - System initialization and boot sequence
  - NVS (Non-Volatile Storage) configuration management
  - WiFi provisioning (BLE or SoftAP based)
  - CAN/TWAI driver initialization and message routing
  - Network service initialization (MQTT, TCP, UDP, Multicast, WebSockets)
  - Web server for configuration interface
  - Event handling for WiFi and provisioning events
  - Main application loop for message distribution

  This file is part of the VSCP (https://www.vscp.org)

  The MIT License (MIT)
  Copyright (C) 2021-2026 Ake Hedman, the VSCP project <info@vscp.org>

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
  THE SOFTWARE IS PROVIDED "AS IS", WITHOUT WARRANTY OF ANY KIND, EXPRESS OR
  IMPLIED, INCLUDING BUT NOT LIMITED TO THE WARRANTIES OF MERCHANTABILITY,
  FITNESS FOR A PARTICULAR PURPOSE AND NONINFRINGEMENT. IN NO EVENT SHALL THE
  AUTHORS OR COPYRIGHT HOLDERS BE LIABLE FOR ANY CLAIM, DAMAGES OR OTHER
  LIABILITY, WHETHER IN AN ACTION OF CONTRACT, TORT OR OTHERWISE, ARISING FROM,
  OUT OF OR IN CONNECTION WITH THE SOFTWARE OR THE USE OR OTHER DEALINGS IN THE
  SOFTWARE.
*/

#include <stdio.h>
#include <string.h>

#include <freertos/FreeRTOS.h>
#include <freertos/event_groups.h>
#include <freertos/queue.h>
#include <freertos/task.h>
#include "freertos/semphr.h"

#include <driver/gpio.h>
#include "esp_task_wdt.h"
#include <esp_twai.h>
#include <esp_event.h>
#include <esp_http_server.h>
#include <esp_log.h>
#include <esp_mac.h>
#include <esp_timer.h>
#include <esp_tls_crypto.h>
#include <esp_wifi.h>
#include <esp_netif.h>
#include <lwip/sockets.h>
#include <lwip/ip4_addr.h>
#include <nvs_flash.h>

#include <network_provisioning/manager.h>

// Components: LED indicator
#include "led_indicator_blink_default.h"
#include "led_indicator_gpio.h"

// Components: Buttons
#include "iot_button.h"
#include "button_gpio.h"

#ifdef CONFIG_WCANG_PROV_TRANSPORT_BLE
#include <network_provisioning/scheme_ble.h>
#endif /* CONFIG_WCANG_PROV_TRANSPORT_BLE */

#ifdef CONFIG_WCANG_PROV_TRANSPORT_SOFTAP
#include <network_provisioning/scheme_softap.h>
#endif /* CONFIG_WCANG_PROV_TRANSPORT_SOFTAP */
#include "qrcode.h"

#include <vscp.h>
#include <vscp-firmware-helper.h>
#include <vscp-crc.h>

#include "can4vscp.h"
#include "tcpsrv.h"
#include "udpsrv.h"
#include "multicastsrv.h"
#include "websrv.h"
#include "websocksrv.h"
#include "mqtt.h"

#include "main.h"

#include "vscp-compiler.h"
#include "vscp-projdefs.h"

static const char *TAG          = "main";
static esp_netif_t *s_sta_netif = NULL;

// ============================================================================
//                           Global Variables
// ============================================================================

// NVS (Non-Volatile Storage) handle for persistent configuration
nvs_handle_t g_nvsHandle;

/**
 * @brief Global persistent configuration structure
 *
 * Contains all device configuration parameters including network settings,
 * CAN parameters, MQTT/UDP/TCP settings, and user credentials. Values are
 * initialized with defaults and loaded from NVS during startup.
 *
 * Modified via web interface and saved to NVS for persistence across reboots.
 */
node_persistent_config_t g_persistent = {
  .nodeName    = DEFAULT_NODE_NAME,
  .nodeZone    = DEFAULT_MODULE_ZONE,
  .nodeSubzone = DEFAULT_MODULE_SUBZONE,
  .guid        = { 0 }, // Default GUID is constructed from MAC address
  .bootCnt     = 0,
  .pmkLen      = 16,                       // AES128 (for future use)
  .pmk         = { 0 },                    // Default key is all nills
  .encryptLvl  = DEFAULT_ENCRYPTION_LEVEL, // 0 = none, 1 = AES128, 2 = AES192, 3 = AES256

  // CAN/TWAI
  .canSpeed  = DEFAULT_CAN_SPEED,
  .canMode   = DEFAULT_CAN_MODE,
  .canFilter = DEFAULT_CAN_FILTER,

  .logType      = DEFAULT_LOG_TYPE,               // Log type
  .logLevel     = DEFAULT_LOG_LEVEL,              // Log level
  .logRetries   = DEFAULT_LOG_RETRIES,            // Number of retries for log message send
  .logPort      = DEFAULT_LOG_PORT,               // Log server port
  .logUrl       = DEFAULT_LOG_URL,                // Log server address
  .logMqttTopic = DEFAULT_MQTT_LOG_PUBLISH_TOPIC, // MQTT topic for log messages

  .webPort     = DEFAULT_WEBSERVER_PORT,
  .webUser     = DEFAULT_WEBSERVER_USER,
  .webPassword = DEFAULT_WEBSERVER_PASSWORD,

  // WiFi
  .wifiPrimarySsid       = "",
  .wifiPrimaryPassword   = "",
  .wifiSecondarySsid     = "",
  .wifiSecondaryPassword = "",
  .wifiStaticEnable      = DEFAULT_WIFI_STATIC_ENABLE,
  .wifiStaticIp          = DEFAULT_WIFI_STATIC_IP,
  .wifiStaticNetmask     = DEFAULT_WIFI_STATIC_NETMASK,
  .wifiStaticGateway     = DEFAULT_WIFI_STATIC_GATEWAY,
  .wifiStaticDns         = DEFAULT_WIFI_STATIC_DNS,

  .enableVscpLink = DEFAULT_VSCP_LINK_ENABLE,
  .vscplinkPort   = DEFAULT_VSCP_LINK_PORT,
  .vscplinkUser   = DEFAULT_VSCP_LINK_USER,
  .vscplinkPw     = DEFAULT_VSCP_LINK_PASSWORD,

  .enableMqtt      = DEFAULT_MQTT_ENABLE,
  .enableMqttTls   = DEFAULT_MQTT_TLS_ENABLE,
  .mqttUrl         = DEFAULT_MQTT_URL,
  .mqttPort        = DEFAULT_MQTT_PORT,
  .mqttUser        = DEFAULT_MQTT_USER,
  .mqttPw          = DEFAULT_MQTT_PASSWORD,
  .mqttPubTopic    = DEFAULT_MQTT_PUBLISH,
  .mqttSubTopic    = DEFAULT_MQTT_SUBSCRIBE,
  .mqttPubLogTopic = DEFAULT_MQTT_LOG_PUBLISH_TOPIC, // Set in logging configuration
  .mqttClientId    = DEFAULT_MQTT_CLIENT_ID,
  .mqttCaCert      = DEFAULT_MQTT_CA_CERT,
  .mqttClientCert  = DEFAULT_MQTT_CLIENT_CERT,
  .mqttClientKey   = DEFAULT_MQTT_CLIENT_KEY,
  .mqttQos         = DEFAULT_MQTT_QOS,
  .mqttRetain      = DEFAULT_MQTT_RETAIN,
  .mqttFormat      = DEFAULT_MQTT_FORMAT,

  // Multicast
  .enableMulticast = DEFAULT_MULTICAST_ENABLE,
  .multicastUrl    = DEFAULT_MULTICAST_URL,
  .multicastPort   = DEFAULT_MULTICAST_PORT,
  .multicastTtl    = DEFAULT_MULTICAST_TTL,
  .bMcastEncrypt   = DEFAULT_MULTICAST_ENCRYPTION,
  .bHeartbeat      = DEFAULT_MULTICAST_HEARTBEAT,

  // UDP
  .enableUdpRx = DEFAULT_UDP_RX_ENABLE,
  .enableUdpTx = DEFAULT_UDP_TX_ENABLE,
  .udpUrl      = DEFAULT_UDP_URL,
  .udpPort     = DEFAULT_UDP_PORT,
  .bUdpEncrypt = DEFAULT_UDP_ENCRYPTION,

  // Websocket server protocol
  .enableWebsock = DEFAULT_WEBSOCKETS_ENABLE,
  .websockPort   = DEFAULT_WEBSOCKETS_PORT,
  .websockUser   = DEFAULT_WEBSOCKETS_USER,
  .websockPw     = DEFAULT_WEBSOCKETS_PASSWORD,
};

static led_indicator_handle_t led_handle_wifi   = NULL;
static led_indicator_handle_t led_handle_status = NULL;

/**
 * @brief Transport layer message queue structures
 *
 * Each transport mechanism (TCP, MQTT, Multicast, UDP, WebSockets) has its own
 * message queue for receiving CAN messages. Messages are distributed from the
 * CAN receive queue to all active transport queues.
 */
transport_t tr_tcpsrv[MAX_TCP_CONNECTIONS] = {}; // TCP/IP VSCP link protocol connections
transport_t tr_mqtt                        = {}; // MQTT client transport
transport_t tr_multicast                   = {}; // Multicast UDP transport
transport_t tr_udp                         = {}; // UDP broadcast transport
transport_t tr_websockets                  = {}; // WebSocket server transport

// Dedicated monitor/command-reply transport - always fed by twai_receive_task
transport_t tr_canapi  = {};
transport_t tr_monitor = {};

// Semaphore for controlling access to main event distribution task
SemaphoreHandle_t ctrl_task_sem;

// ============================================================================
//                        CAN/TWAI Message Queues
// ============================================================================

/**
 * @brief CAN message queues for transmit and receive
 *
 * tr_twai_tx: Outgoing CAN messages from all network interfaces
 * tr_twai_rx: Incoming CAN messages distributed to network interfaces
 */
static QueueHandle_t tr_twai_tx;
static QueueHandle_t tr_twai_rx;

// ============================================================================
//                           Web Server Handle
// ============================================================================

// HTTP server handle for configuration web interface
static httpd_handle_t server_httpd = NULL;

// ============================================================================
//                    WiFi Provisioning Security (Version 2)
// ============================================================================

#if CONFIG_WCANG_PROV_SECURITY_VERSION_2

#if CONFIG_WCANG_PROV_SEC2_DEV_MODE
#define WCANG_PROV_SEC2_USERNAME "testuser"
#define WCANG_PROV_SEC2_PWD      "testpassword"

/**
 * Salt and verifier for SEC2 provisioning authentication
 *
 * This salt/verifier pair has been generated for username = "testuser" and password = "testpassword"
 * IMPORTANT NOTE: For production cases, this must be unique to every device
 * and should come from device manufacturing partition.*/
static const char sec2_salt[] = { 0x2f, 0x3d, 0x3c, 0xf8, 0x0d, 0xbd, 0x0c, 0xa9,
                                  0x6f, 0x30, 0xb4, 0x4d, 0x89, 0xd5, 0x2f, 0x0e };

// 24*16 = 384 * 8 = 3072
static const char sec2_verifier[] = {
  0xf2, 0x9f, 0xc1, 0xf5, 0x28, 0x4a, 0x11, 0x74, 0xb4, 0x24, 0x09, 0x23, 0xd8, 0x27, 0xb7, 0x5a, 0x95, 0x3a, 0x99,
  0xed, 0xf4, 0x6e, 0xe9, 0x8c, 0x4f, 0x07, 0xf2, 0xf5, 0x43, 0x3d, 0x7f, 0x9a, 0x11, 0x60, 0x66, 0xaf, 0xcd, 0xa5,
  0xf6, 0xfa, 0xcb, 0x06, 0xe9, 0xc5, 0x3f, 0x4d, 0x77, 0x16, 0x4c, 0x68, 0x6d, 0x7f, 0x7c, 0xd7, 0xc7, 0x5a, 0x83,
  0xc0, 0xfb, 0x94, 0x2d, 0xa9, 0x60, 0xf0, 0x09, 0x11, 0xa0, 0xe1, 0x95, 0x33, 0xd1, 0x30, 0x7f, 0x82, 0x1b, 0x1b,
  0x0f, 0x6d, 0xf1, 0xdc, 0x93, 0x1c, 0x20, 0xa7, 0xc0, 0x8d, 0x48, 0x38, 0xff, 0x46, 0xb9, 0xaf, 0xf7, 0x93, 0x78,
  0xae, 0xff, 0xb8, 0x3b, 0xdf, 0x99, 0x7b, 0x64, 0x47, 0x02, 0xba, 0x01, 0x39, 0x0f, 0x5c, 0xd8, 0x4e, 0x6f, 0xc8,
  0xd0, 0x82, 0x7f, 0x2d, 0x33, 0x1a, 0x09, 0x65, 0x77, 0x85, 0xbc, 0x8a, 0x84, 0xe0, 0x46, 0x7e, 0x3b, 0x0e, 0x6e,
  0x3b, 0xdf, 0x70, 0x17, 0x70, 0x0a, 0xbc, 0x84, 0x67, 0xfa, 0xf9, 0x84, 0x53, 0xda, 0xb4, 0xca, 0x38, 0x71, 0xe4,
  0x06, 0xf6, 0x7d, 0xc8, 0x32, 0xbb, 0x91, 0x0c, 0xe7, 0xd3, 0x59, 0xb6, 0x03, 0xed, 0x8e, 0x0d, 0x91, 0x9c, 0x09,
  0xd7, 0x6f, 0xd5, 0xca, 0x55, 0xc5, 0x58, 0x0f, 0x95, 0xb5, 0x83, 0x65, 0x6f, 0x2d, 0xbc, 0x94, 0x0f, 0xbb, 0x0f,
  0xd3, 0x42, 0xa5, 0xfe, 0x15, 0x7f, 0xf9, 0xa8, 0x16, 0xe6, 0x58, 0x9b, 0x4c, 0x0f, 0xd3, 0x83, 0x2c, 0xac, 0xe4,
  0xbf, 0xa3, 0x96, 0x1e, 0xb6, 0x6f, 0x59, 0xe6, 0xd1, 0x0e, 0xd4, 0x27, 0xb6, 0x05, 0x34, 0xec, 0x8c, 0xf8, 0x72,
  0xbb, 0x04, 0x7b, 0xa4, 0x49, 0x3d, 0x6d, 0xa9, 0x99, 0xfc, 0x0a, 0x2b, 0xd8, 0x46, 0xa8, 0xd1, 0x46, 0x61, 0x5c,
  0x96, 0xd2, 0x43, 0xcd, 0xea, 0x7f, 0x6a, 0x50, 0x59, 0x0d, 0x0e, 0xa1, 0xb3, 0x94, 0x5a, 0x34, 0xe0, 0x1e, 0x95,
  0x56, 0x68, 0xb4, 0xbc, 0xf1, 0x08, 0x54, 0xcb, 0x42, 0x41, 0xc6, 0x78, 0xad, 0x71, 0x84, 0x1c, 0x29, 0xb8, 0x33,
  0x79, 0x1c, 0x10, 0xdd, 0x07, 0xc8, 0x91, 0x21, 0x85, 0x89, 0x76, 0xd7, 0x37, 0xdf, 0x5b, 0x19, 0x33, 0x4e, 0x17,
  0x67, 0x02, 0x0f, 0x1b, 0xb9, 0x2f, 0xa4, 0xdc, 0xdd, 0x75, 0x32, 0x96, 0x87, 0xdd, 0x66, 0xc3, 0x33, 0xc1, 0xfc,
  0x4c, 0x27, 0x63, 0xb9, 0x14, 0x72, 0x76, 0x65, 0xb8, 0x90, 0x2b, 0xeb, 0x7a, 0xde, 0x71, 0x97, 0xf3, 0x6b, 0xc9,
  0x8e, 0xdf, 0xfc, 0x6e, 0x13, 0xcc, 0x1b, 0x2b, 0x54, 0x1a, 0x6e, 0x3d, 0xe6, 0x1c, 0xec, 0x5d, 0xa1, 0xf1, 0xd4,
  0x86, 0x9d, 0xcd, 0xb9, 0xe8, 0x98, 0xf1, 0xe5, 0x16, 0xa5, 0x48, 0xe5, 0xec, 0x12, 0xe8, 0x17, 0xe2, 0x55, 0xb5,
  0xb3, 0x7c, 0xce, 0xfd
};
#endif

// ============================================================================
//                  Provisioning Security Helper Functions
// ============================================================================

/**
 * @brief Get SEC2 provisioning salt value
 *
 * Returns the salt value used for SEC2 (SRP6a) authentication during WiFi
 * provisioning. In development mode, returns hardcoded test salt. In production
 * mode, should retrieve device-specific salt from secure storage.
 *
 * @param[out] salt      Pointer to store salt buffer address
 * @param[out] salt_len  Pointer to store salt length
 *
 * @return ESP_OK on success, ESP_FAIL if not implemented
 */
static esp_err_t
wcang_get_sec2_salt(const char **salt, uint16_t *salt_len)
{
#if CONFIG_WCANG_PROV_SEC2_DEV_MODE
  ESP_LOGI(TAG, "Development mode: using hard coded salt");
  *salt     = sec2_salt;
  *salt_len = sizeof(sec2_salt);
  return ESP_OK;
#elif CONFIG_WCANG_PROV_SEC2_PROD_MODE
  ESP_LOGE(TAG, "Not implemented!");
  return ESP_FAIL;
#endif
}

/**
 * @brief Get SEC2 provisioning verifier value
 *
 * Returns the verifier value used for SEC2 (SRP6a) authentication during WiFi
 * provisioning. In development mode, returns hardcoded test verifier. In production
 * mode, should retrieve device-specific verifier from secure storage.
 *
 * The verifier is derived from the username, password, and salt using SRP6a protocol.
 *
 * @param[out] verifier      Pointer to store verifier buffer address
 * @param[out] verifier_len  Pointer to store verifier length
 *
 * @return ESP_OK on success, ESP_FAIL if not implemented
 */
static esp_err_t
wcang_get_sec2_verifier(const char **verifier, uint16_t *verifier_len)
{
#if CONFIG_WCANG_PROV_SEC2_DEV_MODE
  ESP_LOGI(TAG, "Development mode: using hard coded verifier");
  *verifier     = sec2_verifier;
  *verifier_len = sizeof(sec2_verifier);
  return ESP_OK;
#elif CONFIG_WCANG_PROV_SEC2_PROD_MODE
  /* This code needs to be updated with appropriate implementation to provide verifier */
  ESP_LOGE(TAG, "Not implemented!");
  return ESP_FAIL;
#endif
}
#endif

static void
init_watchdog_timer(void)
{
  esp_task_wdt_config_t wdt_config = {
    .timeout_ms     = 10000, // 10-second timeout
    .idle_core_mask = 0,     // Monitor all cores
    .trigger_panic  = true   // Trigger panic on timeout
  };

  esp_err_t err = esp_task_wdt_init(&wdt_config);
  if (err == ESP_OK) {
    printf("Task Watchdog Timer initialized successfully.\n");
  }
  else {
    printf("Failed to initialize Task Watchdog Timer: %s\n", esp_err_to_name(err));
  }
}

// ============================================================================
//                    NVS Configuration Management
// ============================================================================
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
void
app_main(void)
{
  esp_err_t ret;

  // Initialize the Task Watchdog Timer
  init_watchdog_timer();

  crcInit(); // For calculating CRC of VSCP events

  // ============================================================================
  //                GPIO Configuration (Status LEDs) ande buttons
  // ============================================================================

  gpio_config_t io_conf = {};

  // Configure LED GPIO pins as outputs without interrupts
  io_conf.intr_type    = GPIO_INTR_DISABLE;   // No interrupts
  io_conf.mode         = GPIO_MODE_OUTPUT;    // Output mode
  io_conf.pin_bit_mask = GPIO_OUTPUT_PIN_SEL; // LED pin mask
  io_conf.pull_down_en = 0;                   // No pull-down
  io_conf.pull_up_en   = 0;                   // No pull-up

  // Apply GPIO configuration
  gpio_config(&io_conf);

  // Initialize status LEDs (active high)
  gpio_set_level(LED_WIFI_GPIO, 1);   // Connection status LED
  gpio_set_level(LED_STATUS_GPIO, 1); // Activity indicator LED

  led_indicator_init(&led_handle_wifi, LED_WIFI_GPIO);
  ret = led_indicator_start(led_handle_wifi, BLINK_CONNECTING);

  led_indicator_init(&led_handle_status, LED_STATUS_GPIO);
  ret = led_indicator_start(led_handle_status, BLINK_FACTORY_RESET);

  // --------------------------------------------------------------------------

  // create gpio button
  const button_config_t btn_cfg           = { 0 };
  const button_gpio_config_t btn_gpio_cfg = {
    .gpio_num     = 0,
    .active_level = 0,
  };
  button_handle_t gpio_btn = NULL;
  ret                      = iot_button_new_gpio_device(&btn_cfg, &btn_gpio_cfg, &gpio_btn);
  if (NULL == gpio_btn) {
    ESP_LOGE(TAG, "Button create failed");
  }

  // vscp_event_t ev = { 0 };
  // ;
  // char *jsonobj = "{\"vscpHead\":321,\"vscpObid\":12345,\"vscpTimeStamp\":67890,\"vscpClass\":10,\"vscpType\":6,"
  //                 "\"vscpGuid\":\"FF:FF:FF:FF:FF:FF:FF:FF:FF:FF:FF:FF:FF:FF:FF\",\"vscpData\":[1,2,3,4,5,6,7,8]}";

  // int result = vscp_fwhlp_parse_json(&ev, jsonobj);
  // ESP_LOGI(TAG,
  //          "Parsed event: status=%d class=%d, type=%d, data_len=%d",
  //          result,
  //          ev.vscp_class,
  //          ev.vscp_type,
  //          ev.sizeData);

  // vscp_event_ex_t pex = { 0 };
  // vscp_fwhlp_parse_json_ex(&pex, jsonobj);
  // ESP_LOGE(TAG,
  //          "Parsed event: status=%d class=%d, type=%d, data_len=%d",
  //          result,
  //          pex.vscp_class,
  //          pex.vscp_type,
  //          pex.sizeData);

  // ============================================================================
  //                      NVS (Non-Volatile Storage) Init
  // ============================================================================

  // Initialize NVS partition for configuration storage
  esp_err_t rv = nvs_flash_init();
  if (rv == ESP_ERR_NVS_NO_FREE_PAGES || rv == ESP_ERR_NVS_NEW_VERSION_FOUND) {
    // NVS partition was truncated or version updated - erase and retry
    ESP_ERROR_CHECK(nvs_flash_erase());
    ESP_ERROR_CHECK(nvs_flash_init());
  }

  // Load all persistent configuration from NVS and increment boot counter
  initPersistentStorage();

  // ============================================================================
  //                      Network Stack Initialization
  // ============================================================================

  // Initialize TCP/IP stack (LwIP)
  ESP_ERROR_CHECK(esp_netif_init());

  // Create default event loop for system events
  ESP_ERROR_CHECK(esp_event_loop_create_default());

  // Create event group for WiFi connection synchronization
  wifi_event_group = xEventGroupCreate();

  // ============================================================================
  //                      FreeRTOS Message Queue Creation
  // ============================================================================

  /**
   * Message queue architecture:
   * - tr_twai_rx: Receives CAN messages from bus (distributed to all transports)
   * - tr_twai_tx: Transmits CAN messages to bus (from all transports)
   * - tr_tcpsrv[]: One queue per TCP connection for VSCP link protocol
   * - tr_mqtt: MQTT transport message queue
   * - tr_multicast: UDP multicast transport queue
   * - tr_udp: UDP unicast/broadcast transport queue
   * - tr_websockets: WebSocket transport queue
   */
  tr_twai_rx = xQueueCreate(10, sizeof(can4vscp_frame_t)); // Incoming CAN messages  <-- from bus
  tr_twai_tx = xQueueCreate(40, sizeof(can4vscp_frame_t)); // Outgoing CAN messages  --> to bus

  // Create message queues for each TCP connection
  for (int i = 0; i < MAX_TCP_CONNECTIONS; i++) {
    tr_tcpsrv[i].tocan_queue   = xQueueCreate(10, sizeof(can4vscp_frame_t));
    tr_tcpsrv[i].fromcan_queue = xQueueCreate(10, sizeof(can4vscp_frame_t));
  }

  // Create message queues for network transports
  tr_mqtt.tocan_queue         = xQueueCreate(10, sizeof(can4vscp_frame_t));
  tr_mqtt.fromcan_queue       = xQueueCreate(10, sizeof(can4vscp_frame_t));
  tr_multicast.tocan_queue    = xQueueCreate(10, sizeof(can4vscp_frame_t));
  tr_multicast.fromcan_queue  = xQueueCreate(10, sizeof(can4vscp_frame_t));
  tr_udp.tocan_queue          = xQueueCreate(10, sizeof(can4vscp_frame_t));
  tr_udp.fromcan_queue        = xQueueCreate(10, sizeof(can4vscp_frame_t));
  tr_websockets.tocan_queue   = xQueueCreate(10, sizeof(can4vscp_frame_t));
  tr_websockets.fromcan_queue = xQueueCreate(10, sizeof(can4vscp_frame_t));

  // HTTP CAN API command/reply queues
  tr_canapi.tocan_queue   = xQueueCreate(10, sizeof(can4vscp_frame_t));
  tr_canapi.fromcan_queue = xQueueCreate(50, sizeof(can4vscp_frame_t));

  // Monitor transport queues (depth 50 buffers bursts between poll intervals)
  tr_monitor.tocan_queue   = xQueueCreate(10, sizeof(can4vscp_frame_t));
  tr_monitor.fromcan_queue = xQueueCreate(50, sizeof(can4vscp_frame_t));

  // Create control semaphore for main task synchronization
  ctrl_task_sem = xSemaphoreCreateBinary();

  // ============================================================================
  //                      WiFi Event Handler Registration
  // ============================================================================

  // Register event handlers for WiFi provisioning, WiFi state, and IP events
  ESP_ERROR_CHECK(esp_event_handler_register(NETWORK_PROV_EVENT, ESP_EVENT_ANY_ID, &event_handler, NULL));
  ESP_ERROR_CHECK(esp_event_handler_register(WIFI_EVENT, ESP_EVENT_ANY_ID, &event_handler, NULL));
  ESP_ERROR_CHECK(esp_event_handler_register(IP_EVENT, IP_EVENT_STA_GOT_IP, &event_handler, NULL));

  // ============================================================================
  //                      WiFi Stack Initialization
  // ============================================================================

  // Create WiFi station network interface
  s_sta_netif = esp_netif_create_default_wifi_sta();
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

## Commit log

2022-09-02 Initial checkin
    [vscp-din-esp32-can-z102-B_Cu.gbr, vscp-din-esp32-can-z102-B_Mask.gbr, vscp-din-esp32-can-z102-B_Paste.gbr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]
2022-09-09 Moved schemas to kiad folder
    [vscp-din-esp32-can-z102.csv, vscp-din-esp32-can-z102.kicad_pcb, vscp-din-esp32-can-z102.kicad_sch]
2022-09-10 rev b schame started canrx moved from gpio10 to gpio3
    [vscp-din-esp32-can-z102.kicad_sch]
2022-09-10 Added images for rev B
    [vscp-din-esp32-can-z102.kicad_pcb, vscp-din-esp32-can-z102.kicad_sch]
2022-09-11 Added provisioning code
    [partitions.csv]
2022-09-14 First part of tcpipsrv
    [partitions.csv]
2022-09-16 txcan routed to Flash pin instead of io8
    [vscp-din-esp32-can-z102.kicad_pcb, vscp-din-esp32-can-z102.kicad_sch]
2022-09-20 J4 moved closer to edge.
    [vscp-din-esp32-can-z102.kicad_pcb]
2022-09-25 Added connector and resistor for BUS_OFF LED connector.
    [vscp-din-esp32-can-z102.kicad_pcb, vscp-din-esp32-can-z102.kicad_sch]
2022-09-28 Changed structure for VCSP Link Protocol Task
    [config.csv, config.txt, vscp-din-esp32-can-z102.kicad_sch]
2023-04-25 Rev B away for production
    [_partions.csv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]
2025-02-18 Updated schema to latest KiCAD
    [vscp-din-esp32-can-z102.kicad_pcb, vscp-din-esp32-can-z102.kicad_sch]
2025-09-17 Added missing firmware files
    [vscp-din-esp32-can-z102.kicad_pcb, vscp-din-esp32-can-z102.kicad_sch]
2025-09-23 Added folder for design documents
    [vscp-din-esp32-can-z102.kicad_pcb, vscp-din-esp32-can-z102.kicad_sch]
2026-01-29 CAN <-> vscp-link working
    [vscp-din-esp32-can-z102.kicad_pcb, vscp-din-esp32-can-z102.kicad_sch]
2026-02-12 CI: set ESP32-C3 flash size to 4MB in [sdkconfig.defaults](http://_vscodecontentref_/0)
2026-03-30 Added label for z102
    [him-card.kicad_pcb, him-card.kicad_sch]
2026-04-07 Added code of conduct
    [him-card.kicad_pcb, vscp-din-esp32-can-z102.kicad_pcb, vscp-din-esp32-can-z102.kicad_sch]
2026-04-09 ws1: fix encrypted binary frame parsing and length recovery
2026-04-09 build: track dependencies lock and untrack managed components
2026-04-09 firmware: pin vscp-firmware CRC macro fix
2026-04-10 Fixed som info values
    [main.c]
2026-04-10 Fixed printf format error
2026-04-13 Option to log to MQTT and UDP
    [vscp-din-esp32-can-z102.kicad_pcb]
2026-04-13 strengthened the disabled styling
    [websrv.h]
2026-04-14 removed main menu button from start page
2026-04-24 Fixed statistics for CAN
    [can4vscp.c]
2026-04-27 Defined status LED colors
    [him-card.kicad_sch, vscp-din-esp32-can-z102.kicad_sch]
2026-04-29 Updated schema
    [vscp-din-esp32-can-z102.kicad_sch]
